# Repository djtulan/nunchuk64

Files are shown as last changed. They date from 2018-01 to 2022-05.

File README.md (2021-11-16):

Nunchuk64

Nunchuk64 is a converter or adapter to connect a Wii Nunchuk or a Nindendo NES Classic Mini Controller
to a Commodore 64. The circuit converts two Nintendo Controllers into two Commodore 64 ones.
All types of the Commodore 64 inputs, which means digital and analog inputs, are available.

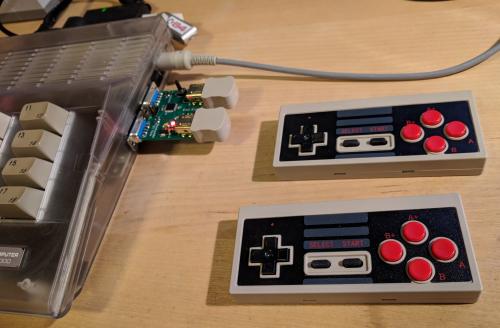
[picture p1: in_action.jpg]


## Introduction Video
User [dukestah] from [Forum64](https://www.forum64.de) made a nice introduction video.
He gives a short introduction how the thing works in basic and demonstrates the functions while playing a game.

INTRODUCITON VIDEO (http://www.youtube.com/watch?v=LK__4W44_HA)

## Layout and PCB
The whole KiCad project is provided inside subfolder ["hardware"](./hardware).

Please feel free to order your own PCBs, Gerber files are here ["gerber"](./hardware/nunchuk64/gerber).

I would be pleased about a small donation: [PAYPAL.ME](https://www.paypal.me/RobertGrasboeck)

If somebody wants order a DIY kit, feel free to contact me: r o b e r t . g r a s b o e c k [at] g m a i l . c o m

## 3D Picture
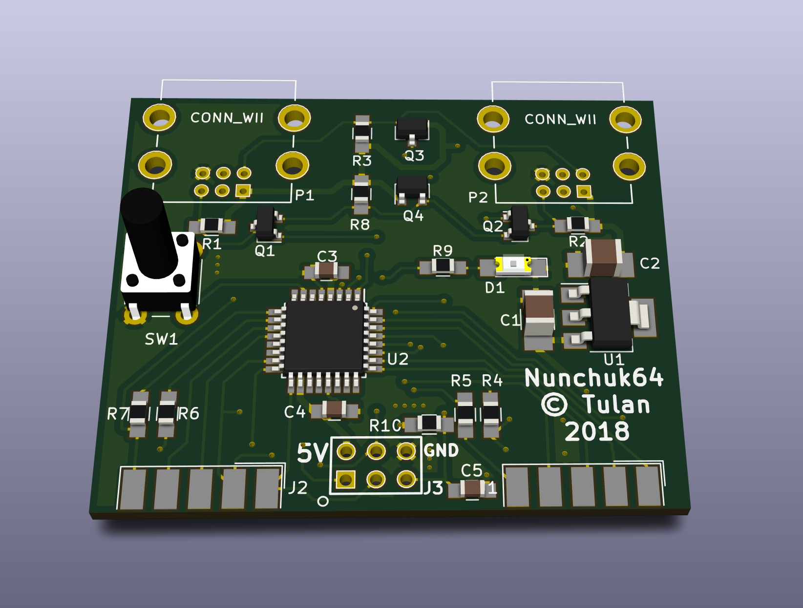
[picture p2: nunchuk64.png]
3d Picture


## Supported and tested Hardware
Currently the following hardware is supported (see [Supported Controllers](./supported_controllers))

## Milestones
- ☑ Tested with a "Nindendo NES Classic Mini Controller" clone
- ☑ Tested with a "original Nindendo Nunchuk Controller"
- ☑ Tested with a "Nindendo Nunchuk Controller" clone
- ☑ Tested with different other NES/SNES Classic Mini clones

## Dependecies
- KiCad to work in schematic and layout (see [KiCad](http://kicad.org/))
- avr-gcc toolchain for compiling the firmware

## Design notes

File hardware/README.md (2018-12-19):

Hardware
==============
In this folder you can find all the needed parts to order the pcb.
The subfolder "nunchuk64" hold the KiCad project and Gerber files.

BOM
---
| Name |Quantity|Value |Footprint |
| ---|---|---|---|
| U1 | 1 |AMS1117-3V3 |SOT-223 |
| U2 | 1 |ATMEGA328P-AU |TQFP-32_7x7mm_Pitch0.8mm |
| C1,C2 | 2 |22uF Tantalum |Tantalum_Case-A_EIA-3216-18 |
| C3,C4,C5 | 3 |100n |0805 |
| D1 | 1 |LED |LED_1206 |
| J1,J2 | 2 |DB9_Female |DSUB-9 EdgeMount_Pitch 2.77mm |
| J3 | 1 |2x3 pin | | 
| P1,P2 | 2 |CONN_WII |Connector_Wii |
| Q1,Q2,Q3,Q4 | 4 |BSS138 |SOT-23 |
| R9 | 1 |220 |0805 |
| R4,R5,R6,R7,R10| 5 |10K |0805 |
| R1,R2,R3,R8 | 4 |2,2K |0805 |
| SW | 1 |SW_Push |Buttons Switch 6mm 13mm lenght|

The ready PCBs
--------------
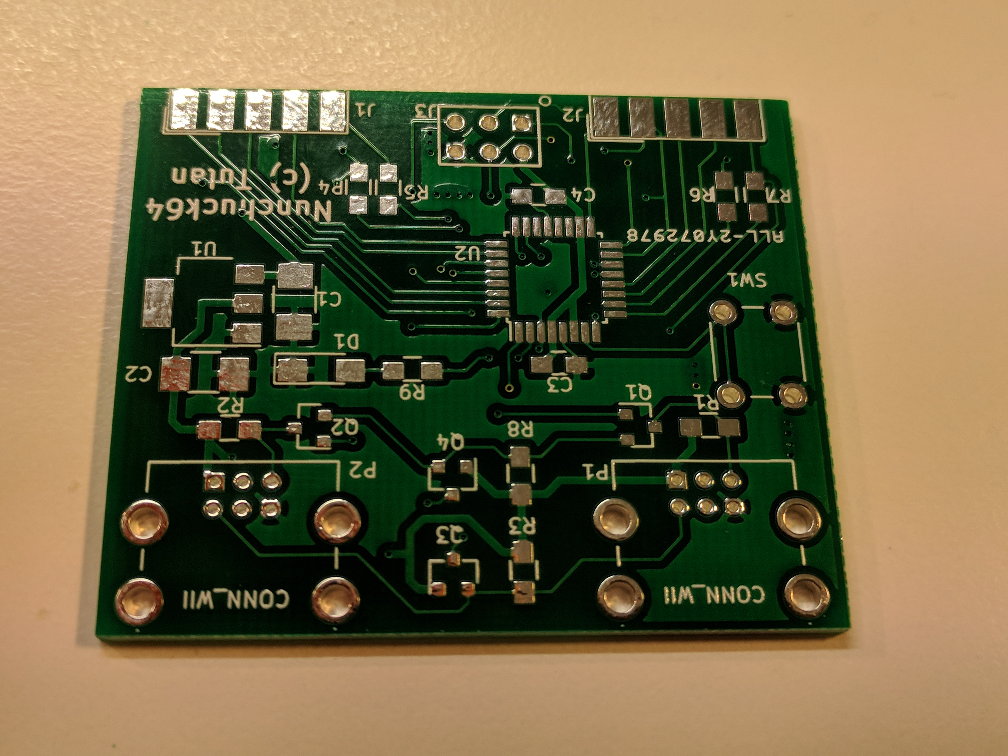
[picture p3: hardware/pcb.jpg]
PCB


PCB with parts
--------------
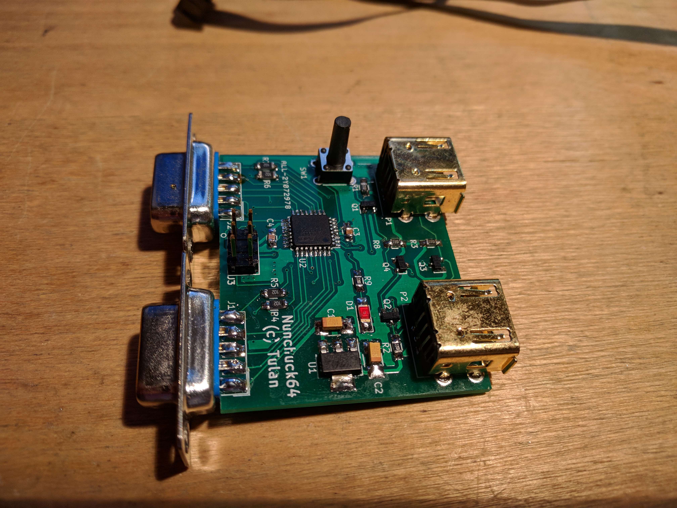
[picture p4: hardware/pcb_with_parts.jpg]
PCB with parts


connected to C64:
--------------
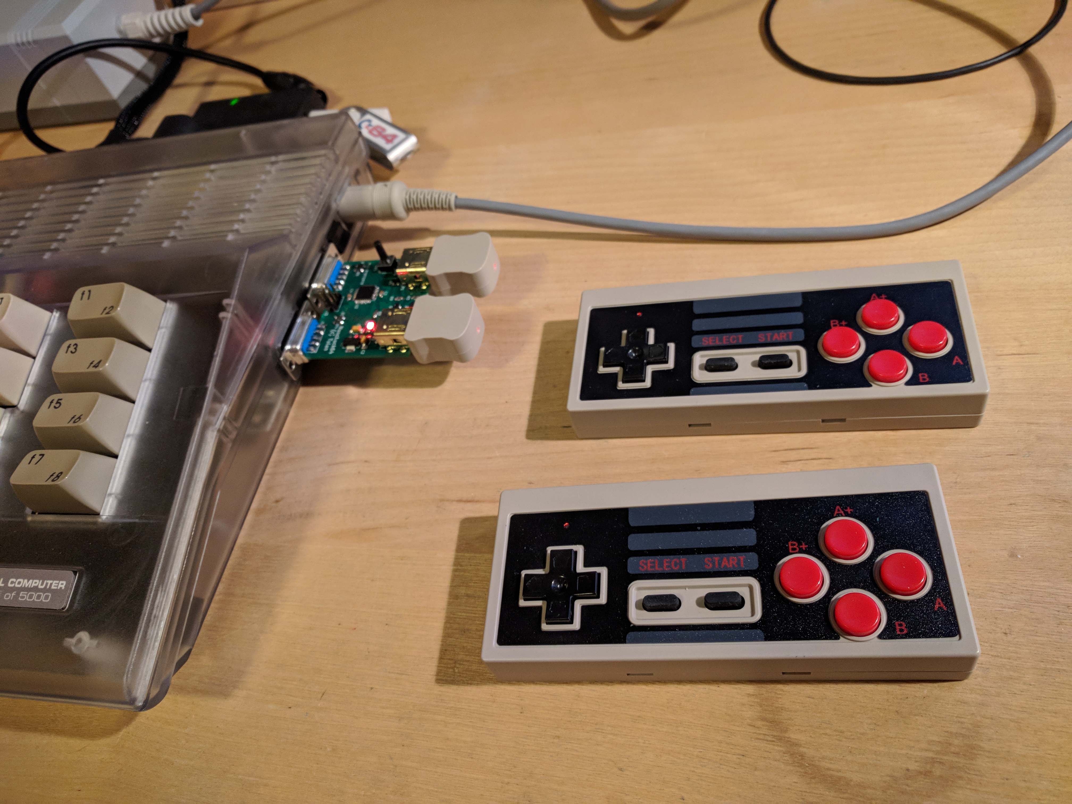
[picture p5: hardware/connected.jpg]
connected


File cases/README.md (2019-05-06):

Nunchuk64 Cases
==============

There are already some cases available for the Nunchuk64.

Case by hackup (https://www.hackup.net/)
----------------------------------------
A realy nice case for friends of 3D printing.
https://www.thingiverse.com/thing:3560915
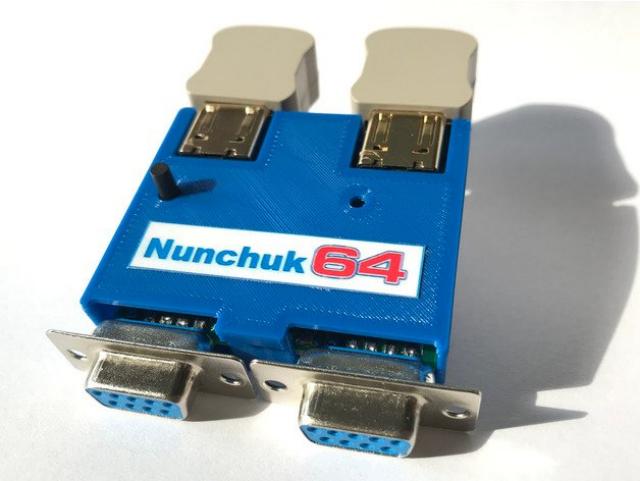
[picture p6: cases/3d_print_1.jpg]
3d_1

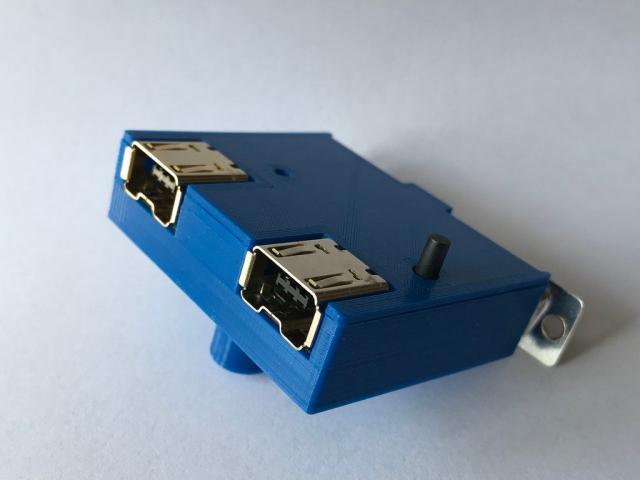
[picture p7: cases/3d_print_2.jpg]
3d_2

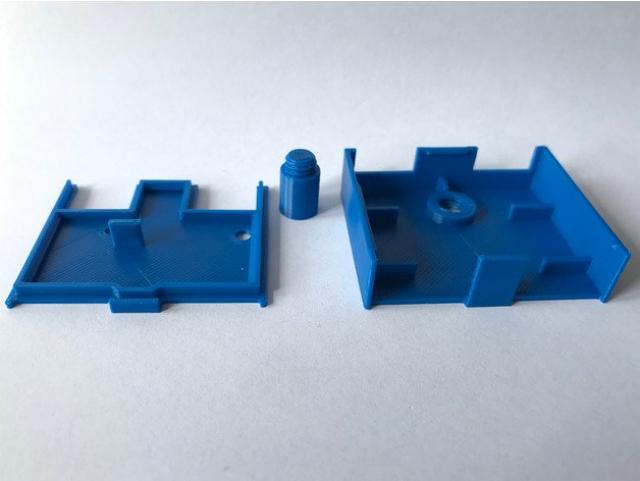
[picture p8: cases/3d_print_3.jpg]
3d_3


Case by plexilaser (Michael Schön)
----------------------------------
A case made from acrylic glass is available at the plexolaser shop:
https://www.plexilaser.de/Acrylgehaeuse-fuer-Nunchuck64-Adapter-Teilesatz

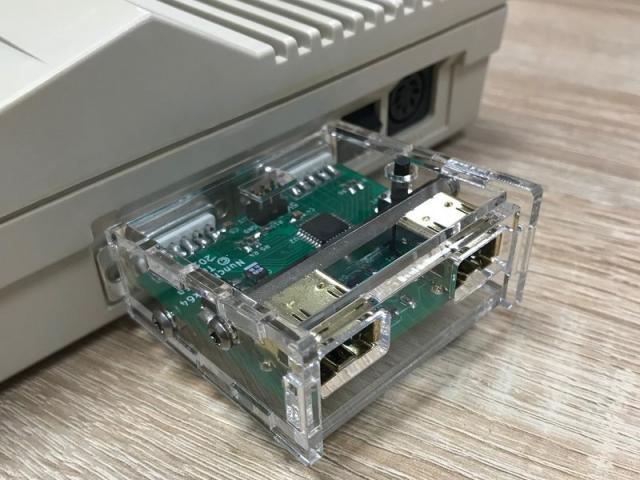
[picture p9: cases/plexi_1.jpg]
plexi_1

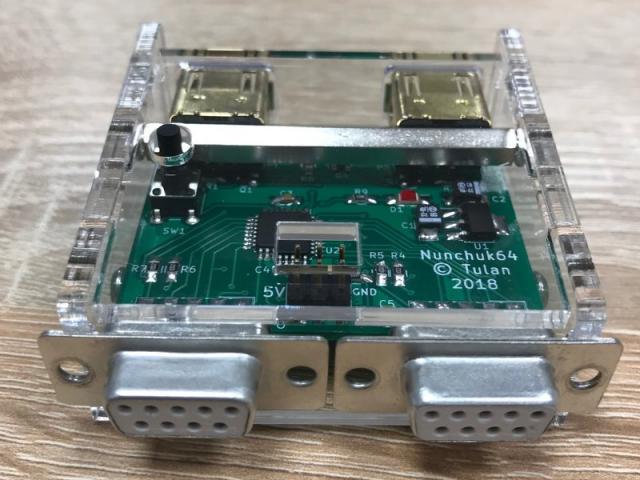
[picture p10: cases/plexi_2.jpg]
plexi_2


Case made from an universal case by Dirk Willke
----------------------------------------------
This nice case is made from a universal case available at conrad.

https://www.conrad.de/de/strapubox-2024-universal-gehaeuse-72-x-50-x-26-abs-schwarz-1-st-522635.html

Strapubox 2024 Universal-Gehäuse 72 x 50 x 26 ABS Schwarz
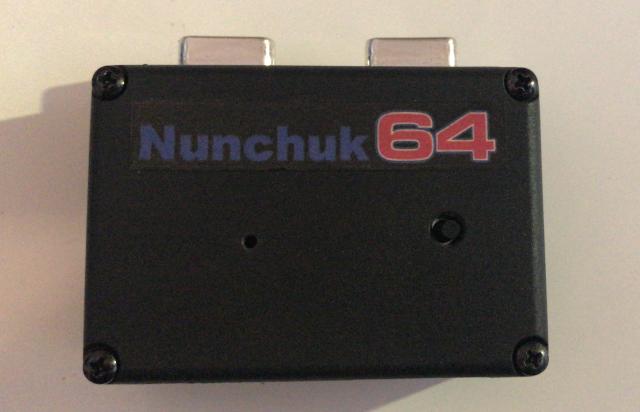
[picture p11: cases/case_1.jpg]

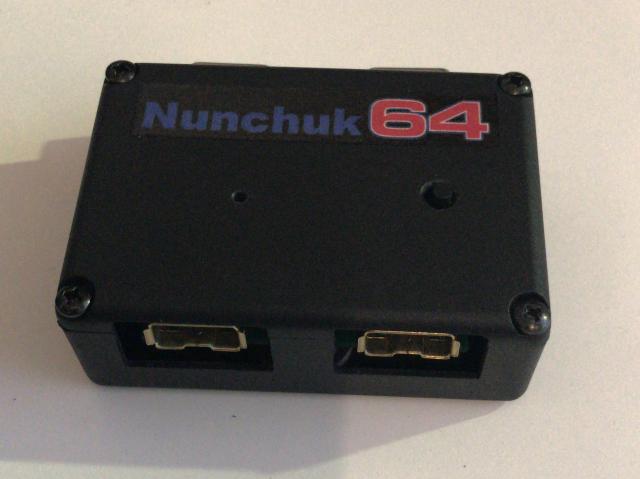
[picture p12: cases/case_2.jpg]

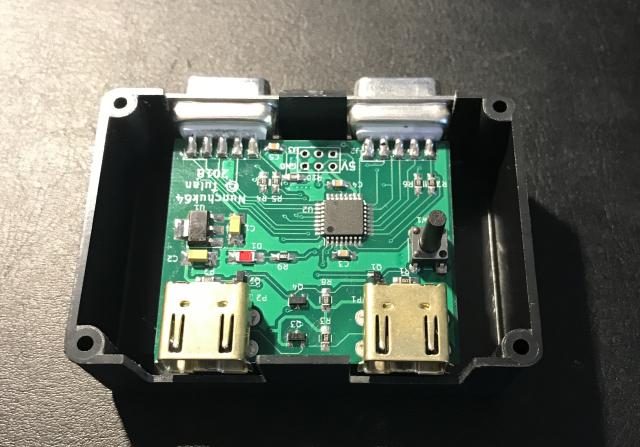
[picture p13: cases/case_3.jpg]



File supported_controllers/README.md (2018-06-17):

# Supported Controllers
This is an overview of all tested controllers.
Since they all mostly use the same datasets, it is very likely that other controllers will work too.

### Modes
Pressing the pushbutton switches the Nunchuk64 to different modes.

- Mode OFF ... LED is OFF
- Mode ON  ... LED is ON
- Mode F1  ... LED flashes 1 time
- Mode F2  ... LED flashes 2 times

Depending on the mode the controllers behaves differently.

### Possible Controls
Nunchuk64 can perform these different controls on each individual C64 Control Port:

- UP (Joystick Up)
- DOWN (Joystick Down)
- LEFT (Joystick Left)
- RIGHT (Joystick Right)
- FIRE (Fire Button)
- AUTOFIRE  (automatic Fire Button)
- PADDLE X
- PADDLE Y
- FIRE2 (5V on Paddle X)
- AUTOFIRE2 BUTTON
- FIRE3 (5V on Paddle Y)
- AUTOFIRE3

An extra function is SPACE, which triggers FIRE on controller port 1.
This is very handy because you can use it to press the space bar.
For FIRE2 / FIRE3 C64s analog paddle input X,Y are used,
similar the Cheetah Annihilator Joystick.
See https://www.c64-wiki.de/wiki/Joystick#Weitere_Feuerkn.C3.B6pfe

### Joystick Swapping
A long press on the button changes the ports. Port 1 becomes 2 and Port 2 becomes 1.
Another long press, changes them back. It is indicated by a two times flash or one time flash.

## NES Classic Mini Clone
Wireless Controller for Nintendo NES Mini Classic Edition.

Seen here: https://www.ebay.com/itm/272765627224
> Button A+ and B+ are same as A and B but with autofire!

> Nintendo original NES Classic Mini is using the driver_wii_classic!

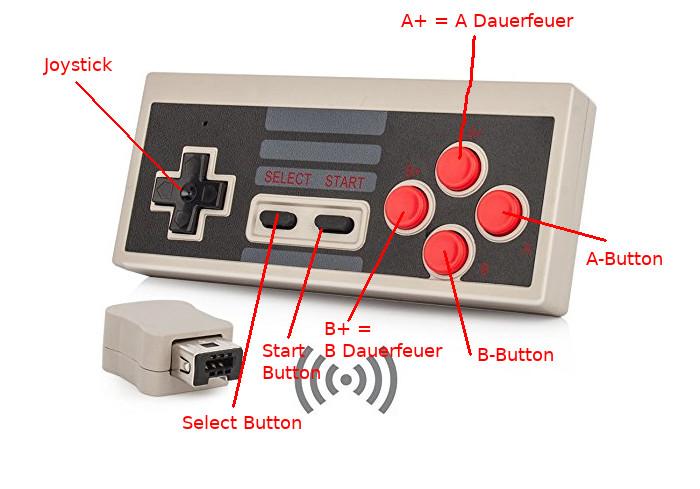
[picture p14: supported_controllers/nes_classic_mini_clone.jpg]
NES Classic Mini Clone


DRIVER: [driver_wii_classic.c]

| Item |Mode OFF  |Mode ON |Mode F1 |Mode F2 |
| ---|---|---|---|---|
| Joystick UP |UP |UP |- |- |
| Joystick DOWN |DOWN |DOWN |- |- |
| Joystick LEFT |LEFT |LEFT |LEFT |- |
| Joystick RIGHT|RIGHT |RIGHT |RIGHT |- |
| A |UP |FIRE2 |UP |LEFT |
| B |FIRE |FIRE |DOWN |RIGHT |
| A+ |UP |FIRE2 |UP |LEFT |
| B+ |FIRE |FIRE |DOWN |RIGHT |
| SELECT |FIRE |FIRE |FIRE |FIRE |
| START |SPACE |SPACE |SPACE |SPACE |

## Original NESS Classic Mini
Wired Controller for Nintendo NES Mini Classic Edition.

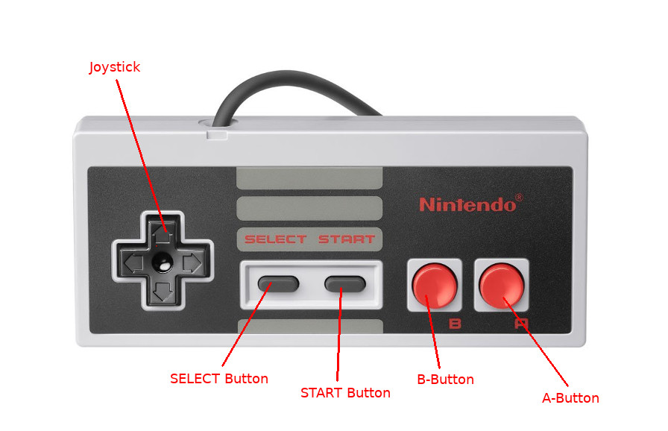
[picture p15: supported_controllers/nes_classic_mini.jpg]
NES Classic Mini


DRIVER: [driver_wii_classic.c]

| Item |Mode OFF  |Mode ON |Mode F1 |Mode F2 |
| ---|---|---|---|---|
| Joystick UP |UP |UP |- |- |
| Joystick DOWN |DOWN |DOWN |- |- |
| Joystick LEFT |LEFT |LEFT |LEFT |- |
| Joystick RIGHT|RIGHT |RIGHT |RIGHT |- |
| A |UP |FIRE2 |UP |LEFT |
| B |FIRE |FIRE |DOWN |RIGHT |
| SELECT |FIRE |FIRE |FIRE |FIRE |
| START |SPACE |SPACE |SPACE |SPACE |

## SNES Classic Mini Clone
Wireless Controller for Nintendo SNES Mini Classic Edition.

Seen here: https://www.ebay.com/itm/162874713501

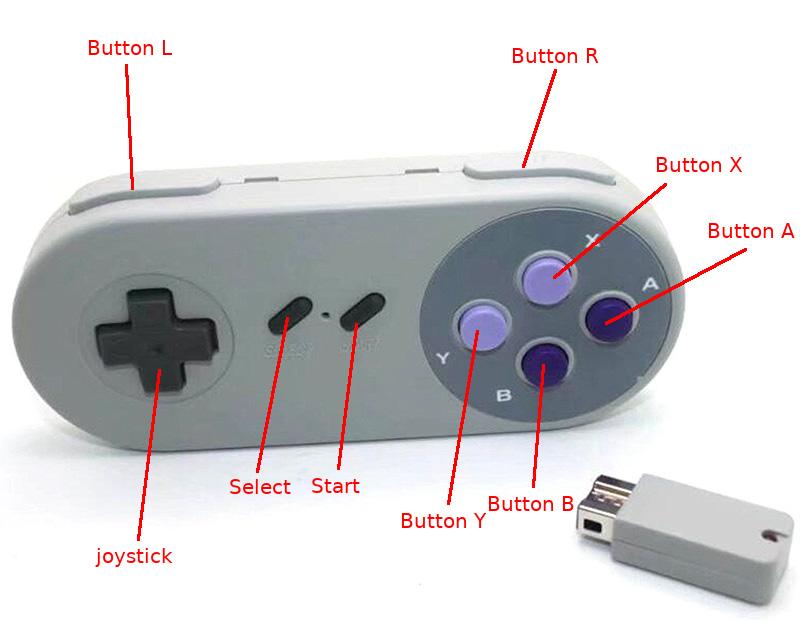
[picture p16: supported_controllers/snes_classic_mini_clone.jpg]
SNES Classic Mini Clone


Wired Controller for Nintendo SNES Mini Classic Edition.

Seen here: https://www.ebay.at/itm/222674575659

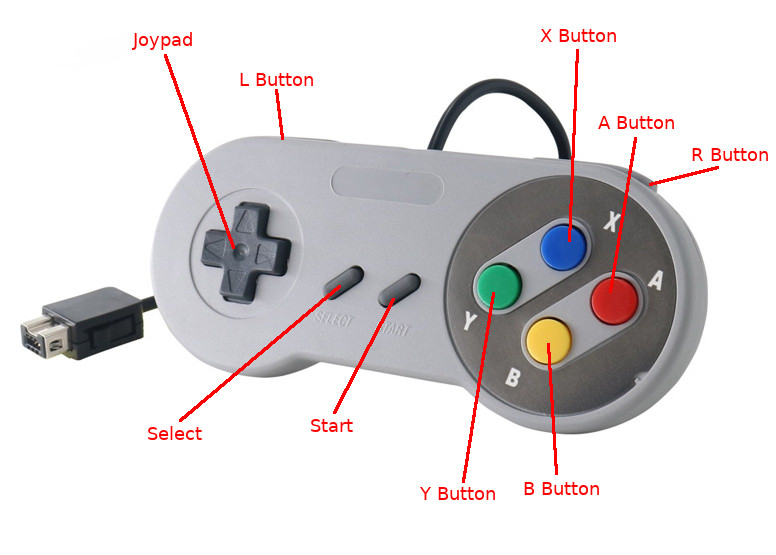
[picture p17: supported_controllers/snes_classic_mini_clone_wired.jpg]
SNES Classic Mini Clone


DRIVER: [driver_wii_classic.c]

| Item |Mode OFF  |Mode ON |Mode F1 |Mode F2 |
| ---|---|---|---|---|
| Joystick UP |UP |UP |- |- |
| Joystick DOWN |DOWN |DOWN |- |- |
| Joystick LEFT |LEFT |LEFT |LEFT |- |
| Joystick RIGHT|RIGHT |RIGHT |RIGHT |- |
| A |UP |FIRE2 |DOWN |RIGHT |
| B |FIRE |FIRE |UP |LEFT |
| X |FIRE2 |FIRE3 |FIRE |FIRE |
| Y |AUTOFIRE  |UP |AUTOFIRE  |- |
| SELECT |FIRE |FIRE |FIRE |FIRE |
| START |SPACE |SPACE |SPACE |SPACE |
| L |LEFT |LEFT |FIRE |- |
| R |RIGHT |RIGHT |FIRE |- |

## Wii classic controller
Wii Classic Controller for Nintendo Wii Remote. (Wired)

Seen here: https://www.ebay.com/itm/291645811767

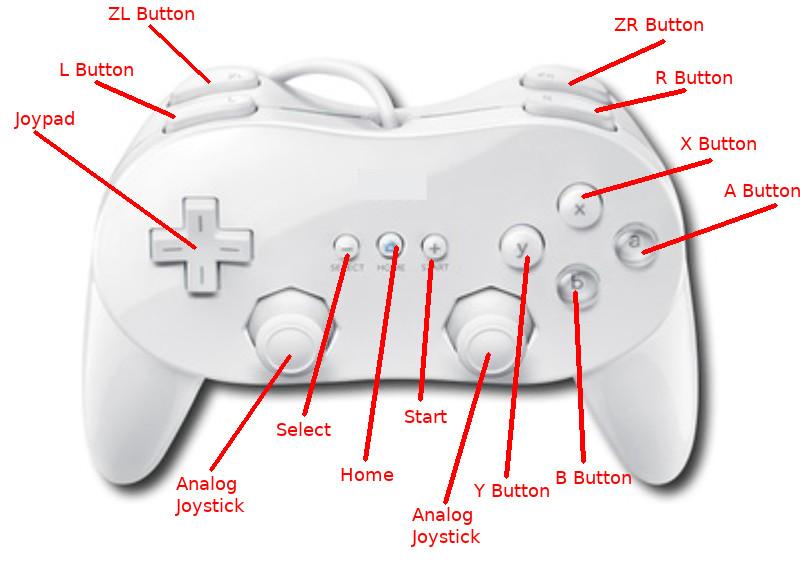
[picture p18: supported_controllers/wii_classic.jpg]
Wii Classic Clone


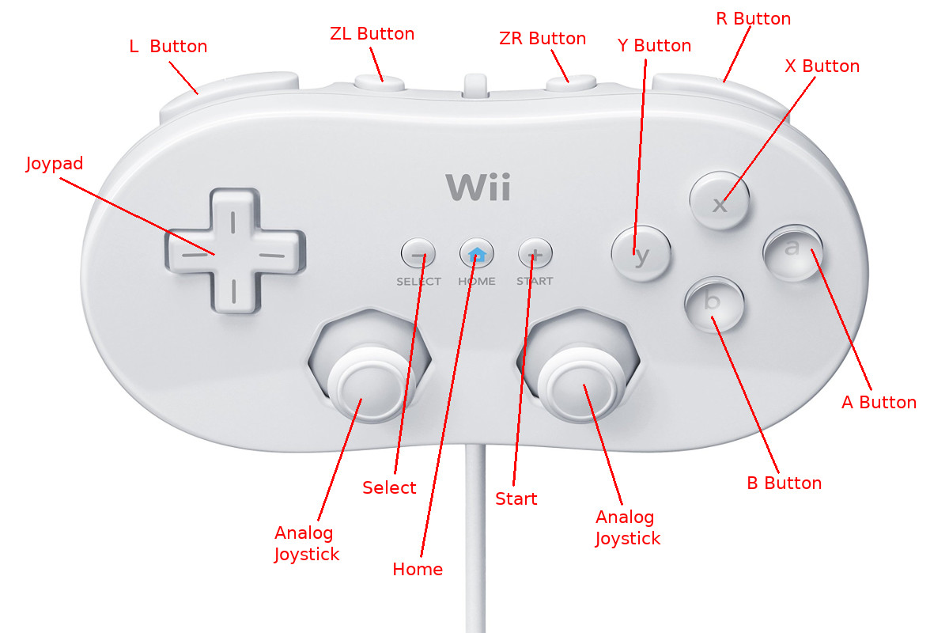
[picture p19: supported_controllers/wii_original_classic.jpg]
Wii Classic


DRIVER: [driver_wii_classic.c]

| Item |Mode OFF  |Mode ON |Mode F1 |Mode F2 |
| ---|---|---|---|---|
| Joystick UP |UP |UP |- |- |
| Joystick DOWN |DOWN |DOWN |- |- |
| Joystick LEFT |LEFT |LEFT |LEFT |- |
| Joystick RIGHT|RIGHT |RIGHT |RIGHT |- |
| A |UP |FIRE2 |DOWN |RIGHT |
| B |FIRE |FIRE |UP |LEFT |
| X |FIRE2 |FIRE3 |FIRE |FIRE |
| Y |AUTOFIRE  |UP |AUTOFIRE  |- |
| SELECT |FIRE |FIRE |FIRE |FIRE |
| HOME |FIRE2 |FIRE2 |FIRE2 |- |
| START |SPACE |SPACE |SPACE |SPACE |
| L |LEFT |LEFT |FIRE |- |
| ZL |- |- |- |- |
| R |RIGHT |RIGHT |FIRE |- |
| ZR |- |- |- |- |
| LX (Analog) |LEFT/RIGHT|LEFT/RIGHT|LEFT/RIGHT|PADDLE X  |
| LY (Analog) |UP/DOWN |UP/DOWN |UP/DOWN |PADDLE Y  |
| RX (Analog) |- |- |- |- |
| RY (Analog) |- |- |- |- |

## Wii Nunchuck
Wii Nunchuck Controller for Nintendo Wii Remote

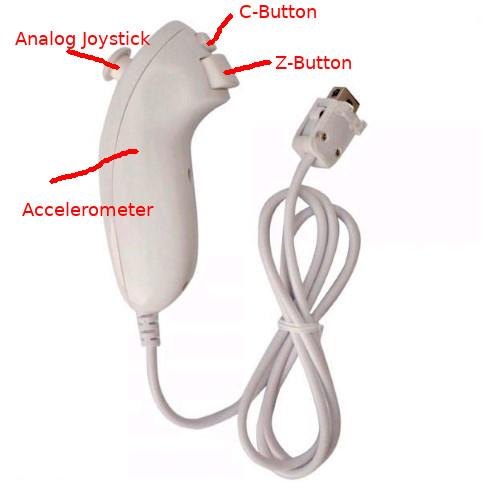
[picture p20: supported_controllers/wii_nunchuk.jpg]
Wii Nunchuk


DRIVER: driver_nunchuk.c

| Item |Mode OFF  |Mode ON |Mode F1 |Mode F2 |
| ---|---|---|---|---|
| Analog Joy X  |LEFT/RIGHT|- |- |PADDLE X  |
| Analog Joy Y  |UP/DOWN |- |- |PADDLE Y  |
| Accel X |- |LEFT/RIGHT|PADDLE X  |- |
| Accel Y |- |UP/DOWN |PADDLE Y  |- |
| Accel Z |- |- |- |- |
| C |AUTOFIRE  |AUTOFIRE  |AUTOFIRE  |AUTOFIRE  |
| Z |FIRE |FIRE |FIRE |FIRE |

[driver_nes_classic.c]: <https://github.com/djtulan/nunchuk64/blob/master/src/driver_nes_classic.c>
[driver_wii_classic.c]: <https://github.com/djtulan/nunchuk64/blob/master/src/driver_wii_classic.c>

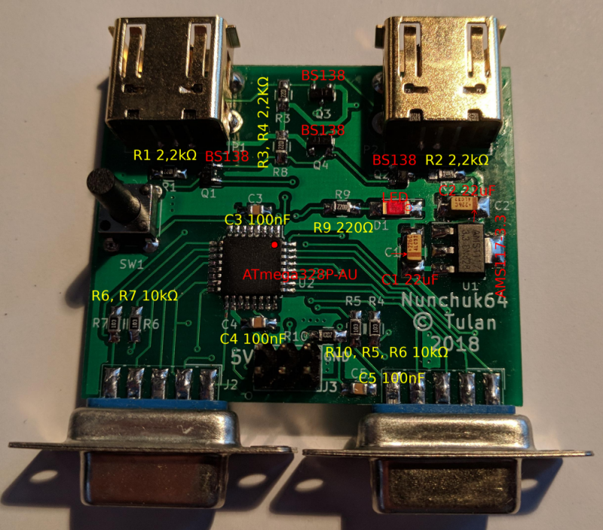
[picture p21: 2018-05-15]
hardware/part_placement.png

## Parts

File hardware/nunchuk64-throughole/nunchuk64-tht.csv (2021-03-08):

Item | Qty | Reference(s) | Value | Footprint | Mouser
1 | 2 | C1, C2 | 22uF | Capacitor_THT:CP_Radial_D5.0mm_P2.50mm | 667-ECE-A1CKS220I
2 | 2 | C3, C5 | 100nF | Capacitor_THT:C_Disc_D5.0mm_W2.5mm_P5.00mm | 594-K104K15X7RF53H5
3 | 1 | D1 | LED | LED_THT:LED_D3.0mm | 859-LTL-4291N
4 | 2 | J1, J2 | DB9_Female | Connectors_DSub:DSUB-9_Female_EdgeMount_Pitch2.77mm | 523-L77SDEH09SOL2RM5
5 | 1 | J3 | Not Used | nunchuk_commodore:AVR-ISP-6-TH
6 | 2 | P1, P2 | CONN_WII | Connector_Wii:CONN_WII
7 | 4 | Q1, Q2, Q3, Q4 | 2N7000 | Package_TO_SOT_THT:TO-92 | 512-2N7000
8 | 1 | R9 | 220 | Resistor_THT:R_Axial_DIN0207_L6.3mm_D2.5mm_P7.62mm_Horizontal | 71-CCF07220RJKE36
9 | 1 | R10 | 10k | Resistor_THT:R_Axial_DIN0207_L6.3mm_D2.5mm_P7.62mm_Horizontal | 71-CCF0710K0JKE36
10 | 1 | RN1 | 2K2 | Resistor_THT:R_Array_SIP5 BUSSED | 652-4605XAP1-222LF
11 | 1 | RN2 | 10K_Pack04_SIP | Resistor_THT:R_Array_SIP8 BUSSED | 652-4608M-2LF-10K
12 | 1 | SW1 | SW_Push | Buttons_Switches_ThroughHole:SW_PUSH_6mm_h13mm | 706-95C06B3T
13 | 1 | U1 | LP2950-3.3_TO92 | Package_TO_SOT_THT:TO-92_Inline | 595-LP2950-33LPRE3
14 | 1 | U2 | ATmega328P-PU | Package_DIP:DIP-28_W7.62mm | 556-ATMEGA328P-PN

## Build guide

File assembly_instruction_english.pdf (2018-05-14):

Brief instructions building Nunchuk64 (https://www.forum64.de/index.php?thread/80731-sammelbestellung-nunchuk64/)

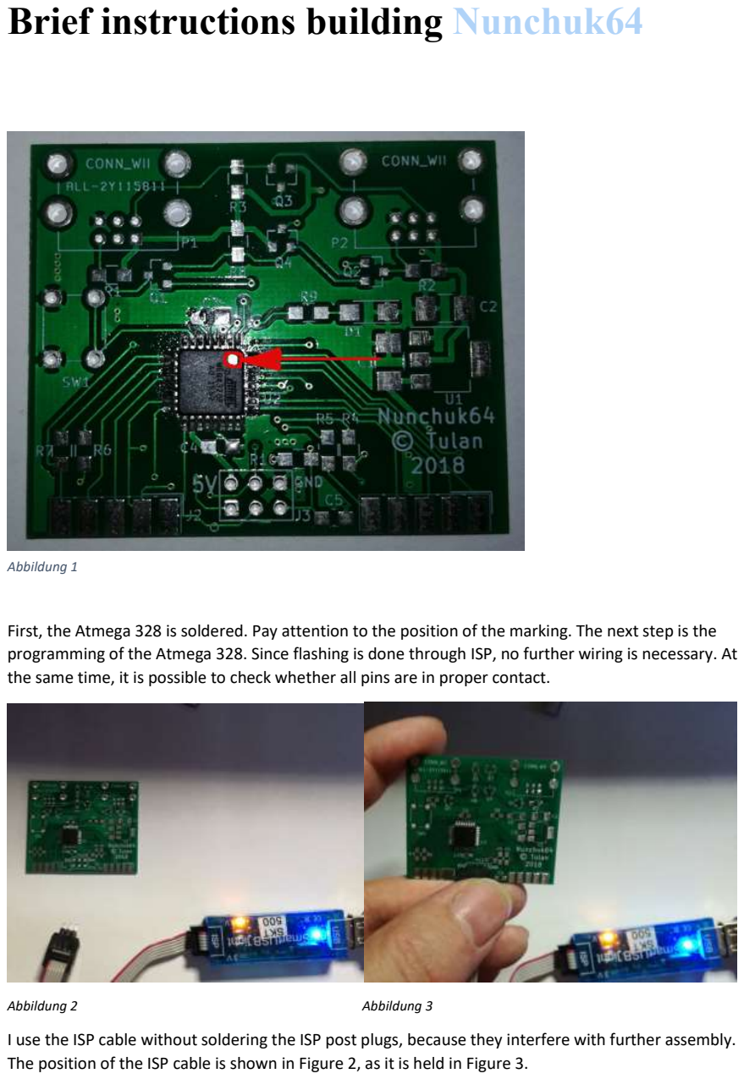
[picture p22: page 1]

Als

First, the Atmega 328 is soldered. Pay attention to the position of the marking. The next step is the programming of the Atmega 328. Since flashing is done through ISP, no further wiring is necessary. At the same time, it is possible to check whether all pins are in proper contact.

Abbildung 2 | Abbildung 3

I use the ISP cable without soldering the ISP post plugs, because they interfere with further assembly. The position of the ISP cable is shown in Figure 2, as it is held in Figure 3.

Abbildung 1

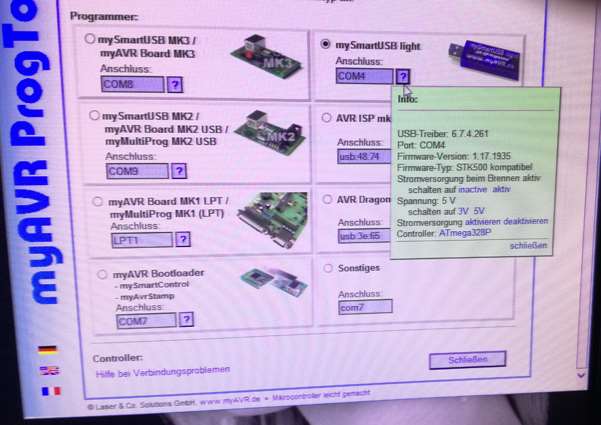
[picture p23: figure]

I am flashing the whole thing with mySmartUSB light. In the tool, click on the question mark. If everything is soldered correctly, the recognized controller appears in the info box. Click on the controller the ATmega328 to take it for programming. In the program menu, select the hex file. Disable the burning of the fuses. (Factory settings are retained)

Similarly, the whole thing works with the TL866 in ISP mode.

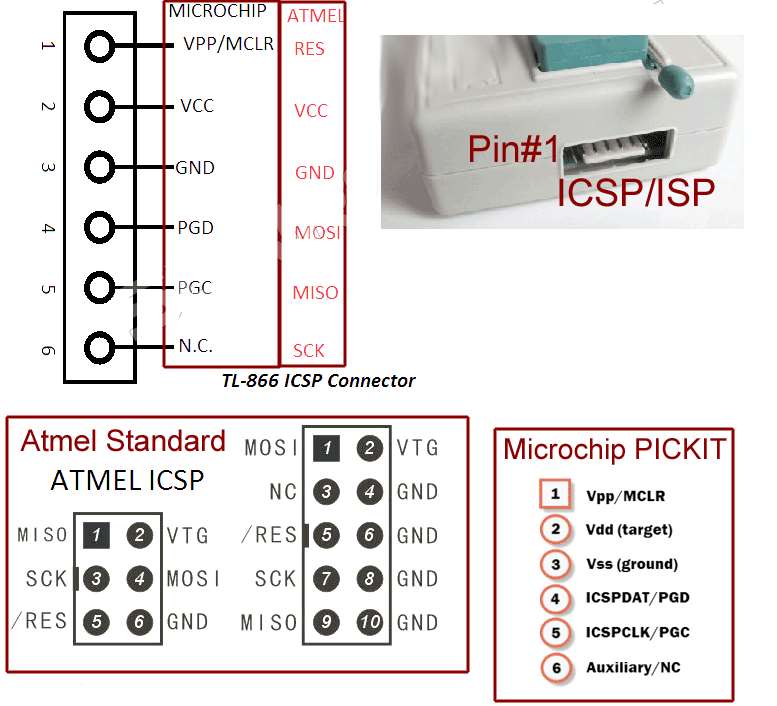
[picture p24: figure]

If you work with avr-dude:
avrdude.exe -c usbasp -p m328p -u -U flash:w:nunchuk64.hex

Please note that the ATMega has to be supplied with power during burning (Jumper "VTarget").

For all who flash their ATMEGA with USBasp, please set the jumper for "Slow SCK", otherwise avrdude does not find the chip. In my case that was JP3.

After flashing, the resistors are assembled:
R1, R2, R3, R8 | 2,2 Kohm
R4, R5, R6, R7, R10 | 10 Kohm
R9 | (dropping resistor LED) 220 Ohm

Then the capacitors:

C1, C2 | 22 µF - Pay attention to polarity!

Polarity of SMD-capacitors

C3, C4, C5 | 100 nF

Now the LED follows:

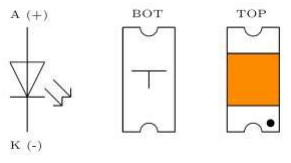
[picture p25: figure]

The tiny point (cathode = - pole) can only be seen before soldering! If you are not sure, you should find the polarity with a 5V source and a 220 ohm resistor.
Then the 3.3V regulator and the 4 transistors are soldered. Finally, the WII sockets,
the 9-pin-sockets, the ISP header and the 4 buttons are soldered in place.

Note on the Sub9 sockets: Solder the first socket at two points. Attach the second one without soldering and connect the board to the C64 with both connectors to achieve the correct distance. Solder the second jack as well. Now the adapter can be removed to solder the remaining pins.

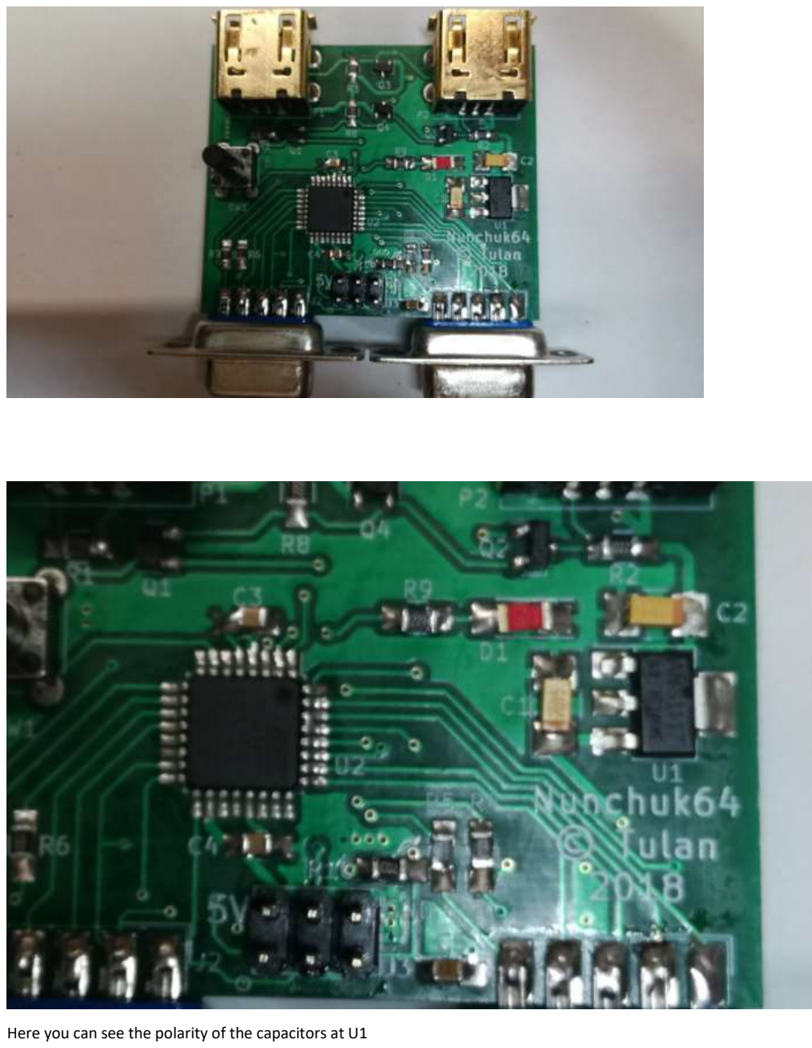
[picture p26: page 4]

Here you can see the polarity of the capacitors at U1

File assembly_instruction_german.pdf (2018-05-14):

Kurzanleitung Aufbau Nunchuk64 (https://www.forum64.de/index.php?thread/80731-sammelbestellung-nunchuk64/)

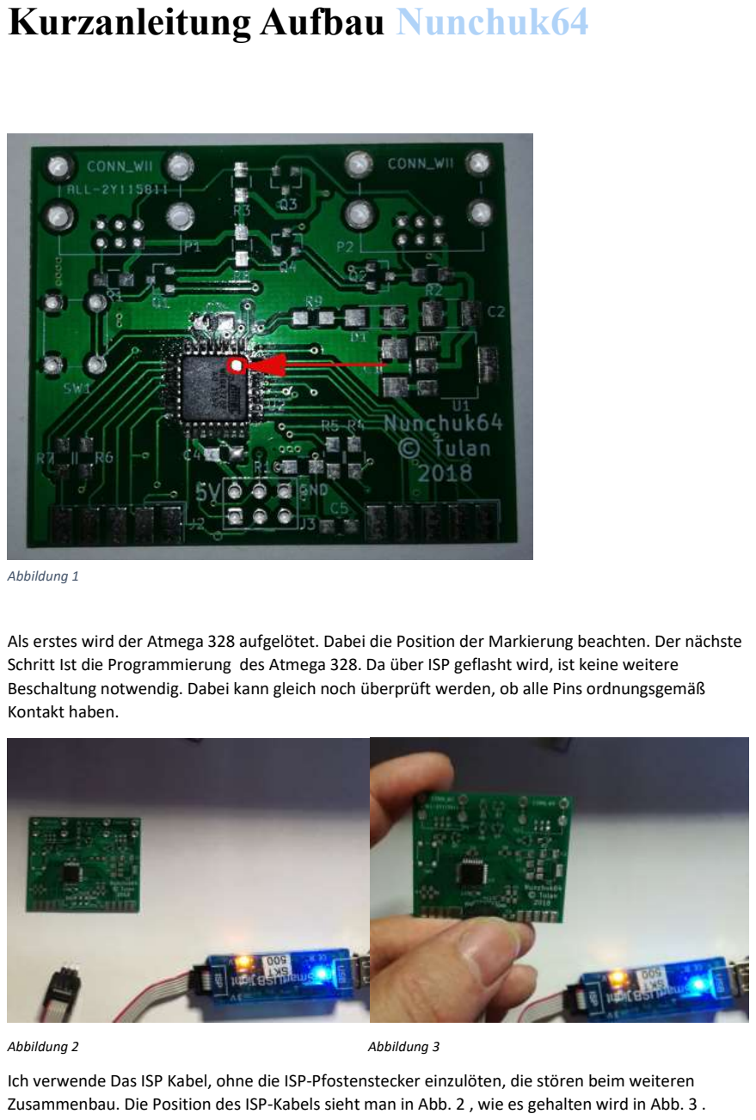
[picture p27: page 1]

Als

Als erstes wird der Atmega 328 aufgelötet. Dabei die Position der Markierung beachten. Der nächste Schritt Ist die Programmierung des Atmega 328. Da über ISP geflasht wird, ist keine weitere Beschaltung notwendig. Dabei kann gleich noch überprüft werden, ob alle Pins ordnungsgemäß Kontakt haben.

Abbildung 2 | Abbildung 3

Ich verwende Das ISP Kabel, ohne die ISP-Pfostenstecker einzulöten, die stören beim weiteren Zusammenbau. Die Position des ISP-Kabels sieht man in Abb. 2 , wie es gehalten wird in Abb. 3 .

Abbildung 1

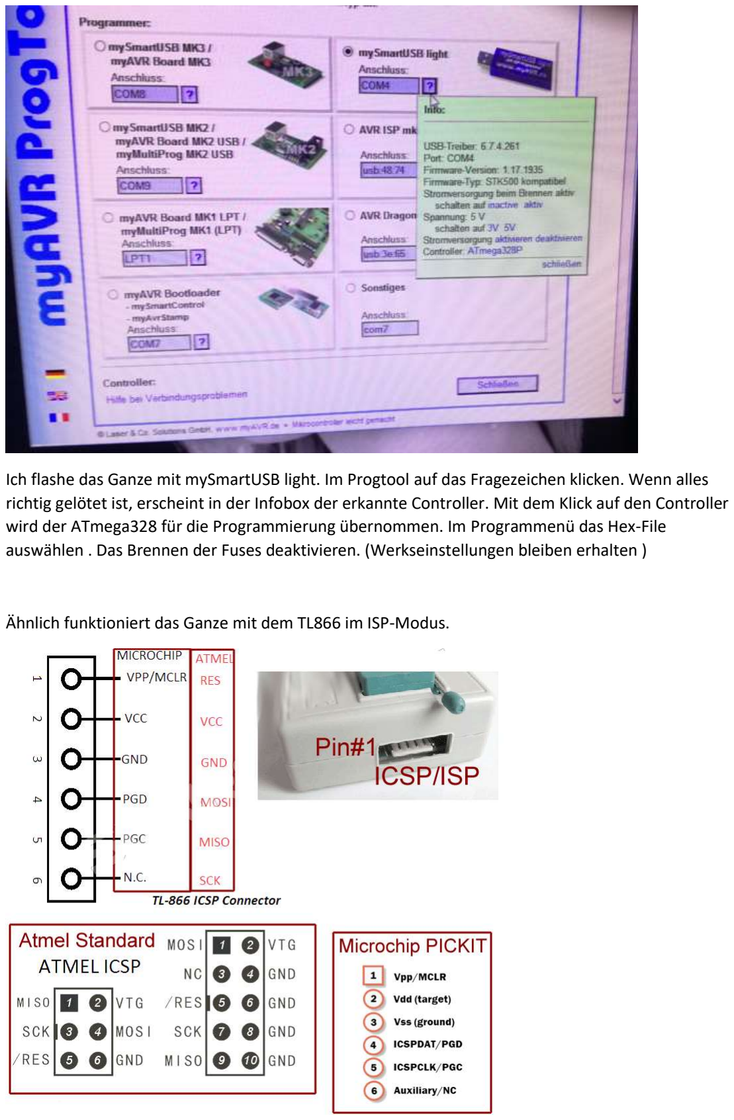
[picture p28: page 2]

Ich flashe das Ganze mit mySmartUSB light. Im Progtool auf das Fragezeichen klicken. Wenn alles richtig gelötet ist, erscheint in der Infobox der erkannte Controller. Mit dem Klick auf den Controller wird der ATmega328 für die Programmierung übernommen. Im Programmenü das Hex-File auswählen . Das Brennen der Fuses deaktivieren. (Werkseinstellungen bleiben erhalten )

Ähnlich funktioniert das Ganze mit dem TL866 im ISP-Modus.

Wer mit avr-Dude arbeitet:
avrdude.exe -c usbasp -p m328p -u -U flash:w:nunchuk64.hex
Bitte beachten, dass der ATMega während des Brennens mit Spannung versorgt werden muss (entsprechenden Jumper "VTarget" setzen).

Für alle, die ihren ATMEGA mit USBasp flashen, bitte den Jumper für "Slow SCK" setzen, sonst findet avrdude den Chip nicht. In meinem Fall war das JP3.

Nach dem Flashen werden die Widerstände bestückt:
R1, R2, R3, R8 | 2,2 Kohm
R4, R5, R6, R7, R10 | 10 Kohm
R9 | (Vorwiderstand LED) | 220 Ohm

Danach die Kondensatoren:

C1, C2 | | 22 µF - Polung beachten !

Polung von SMD-Kondensatoren

C3, C4, C5 | 100 nF

Jetzt folgt die LED:

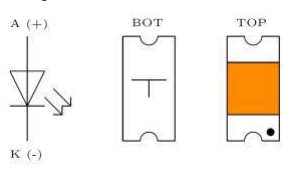
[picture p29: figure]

Den winzigen Punkt ( Kathode = - Pol )sieht man nur vor dem Löten ! Wer sich nicht sicher ist, sollte die Polung mit einer 5V Quelle und einem 220 Ohm Vorwiderstand herausfinden.

Danach wird der 3,3V Regler und die 4 Transistoren eingelötet.

Zum Schluss werden Die WII-Buchsen, Die 9-pol-Buchsen, der ISP- Header und der Microtaster eingelötet.
Hinweis zu den Sub9 – Buchsen: Erst mal eine Buchse an zwei Punkten anheften und die zweite nur aufstecken. Dann am C64 anschließen ( wegen der Abstände) und dann die zweite Buchse ebenfalls anheften. Nun kann der Adapter vom C64 entfernt werden und die restlichen Lötstellen gelötet werden.

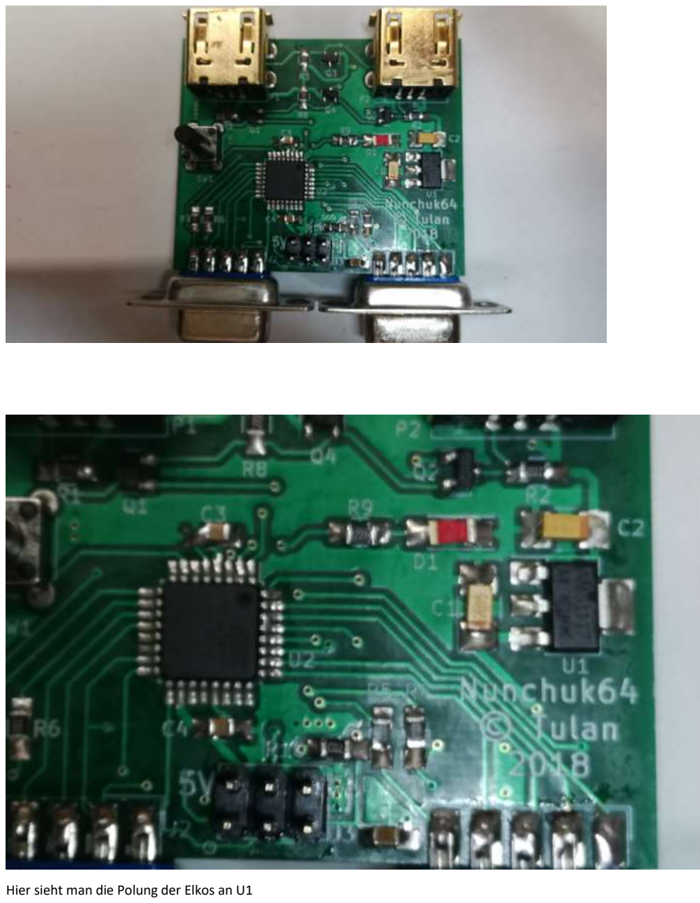
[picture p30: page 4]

Hier sieht man die Polung der Elkos an U1

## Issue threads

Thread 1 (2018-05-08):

8bitdo Controllers are not recognized

djtulan, 2018-05-08:
The famous 8Bitdo wireless controllers for Wii and Nintendo NES classic Mini are sadly not regonized.

djtulan, 2018-05-15:
- Fixed with Release 1.1.0

Closed 2018-05-15.

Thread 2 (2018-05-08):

new (black) Nunchuks are not working

djtulan, 2018-05-08:
Some of the original Nintendo Nunchuks are not working yet.

djtulan, 2018-08-23:
Since the newer Nunchuks (also for Wii U) need a higher I²C speed. It cannot be reached with the ATmega.

penfold42, 2019-10-16:
I know this is an old issue...

What i2c clock do they need ?
Would running the avr at 8MHz help ?

Closed 2018-08-23.

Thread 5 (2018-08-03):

tl866a fusebits risc of locking oneself out. Should be in the docs.

bwack, 2018-08-03:
I'm making a handful of the boards and programming them with the TL866A.
Half of the boards programmed fine, but the rest did not.
After research it was the fusebits in minipro that got changed. Also I got them back to life by supplying a clock signal in on the button/XTAL and reprogramming them.

I thought the .hex file carried the fusebits, but no. These have to be set manually, and I found them in the makefile.  Could you please put the fusebits information in the programming documentation and together with the instructions for using tl866a?

djtulan, 2018-08-23:
bwack is absolutely right. Take care of the fusebits. Best is not to play around with it. Leave the default fusebits for ATmega328p.

bwack, 2018-09-06:
Maybe it is not the correct place to ask, but did you write the I2C communication yourself ? I'm looking into adding I2C on an ATTINY for my c64 saver addon board project.

Closed 2022-05-26.

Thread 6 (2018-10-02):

LED is flashing only, no function

VintageProject, 2018-10-02:
When trying the Nunchuk64 with Nintendo Nunchuks, I found that the LED is flashing constantly with approx. 1 Hz, much like the basic Blinky program. The flashing happens no matter if a C64 is hooked up or a Nunchuk.
If I power the board from a bench PSU with 5V via the DB9 or the programming header, it also flashes.

Although I read that the LED on pin 2 of the ATMega328P is hooked up for debugging, I couldn't find any documentation on how to read its signal.

What does this constant flashing mean?

I tried reprogramming the MCU with this v1.2.0 release, but it didn't change.
https://github.com/djtulan/nunchuk64/releases

djtulan, 2018-10-03:
The Flashing comes from the Watchdog Timer, which is set to 1sec.
The WDT resets the device if the I2C communication times out -> no anwer.
If no controller is connected and the device flashes with 1Hz, then you have a soldering bug.
Some newer Nunchuks don't work with the Adapter, this could be the issue.

bwack, 2019-10-16:
@VintageProject Are your Nunchucks the black ones with higher I2C frequencies ? Maybe realted issue #2.

VintageProject, 2019-10-17:
@bwack Yes, they're black oney, but I didn't get around measuring anything or diving into the code.
I did test with another controller, and the faulty board didn't seem to work with that, either.

bwack, 2019-10-18:
Faulty board.. I sent two working boards!

VintageProject, 2019-10-18:
You did. I think the microcontroller got knackered somehow.
I have replacements somewhere and I'm going to try and swap it.

As for the function with the Nunchuks, we can close this one here.

Closed 2019-10-18.

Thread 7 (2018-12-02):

Ready made HEX

mamejay, 2018-12-02:
Hello there.  I am good at soldering but terrible on the software side and not sure about compiling the source code.  I am a windows user and have no idea where to start.
Is it possible to get a ready made HEX file for the Atmega chip?
Also on a previous issue you mention to just leave all fuse values alone.  so if using AVRdude I would just use a standard command and leave all fuse values out of the command?
Thanks

djtulan, 2018-12-03:
You don't have to compile it by yourself you can just use the latest release:
https://github.com/djtulan/nunchuk64/releases
There is also the HEX file.

The call for avrdude should look like this, depending on your programmer
I don't know if it is the same for Windows
**avrdude -p atmega328p -c usbtiny -F -v  -v  -U flash:w:nunchuk64.hex**

mamejay, 2018-12-03:
Thank you very much for that.  I feel a bit silly now.

Closed 2018-12-03.

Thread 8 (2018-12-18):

Huge lag on Left and down movements

mamejay, 2018-12-18:
Hi there djtulan.
I managed to make a couple of adapters last night.
They are recognising but I am getting huge lag on left and down movement.  Also slight lag on all other movements but left and down is the worst.
I purchased the following SNES mini controllers.
https://www.ebay.com.au/itm/Wireless-Controller-Gamepad-For-Super-Nintendo-SNES-Classic-Mini-Edition-Console/222907612359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

Any ideas on what could be the issue?  I have use 22uf ceramic caps.  Could this be the issue?
Everything else is exactly as you had in your BOM.  Thanks

djtulan, 2018-12-18:
Hi!

I also got some of these. The quality is not so nice. Do you have always the same lag or is it changing? Maybe it is a contact problem inside the controller? One of mine had troubles with one direction as i remember right. I opened the controller and moved the membrane to the correct position, than it was slightly better.

The 22uF ceramic caps should not cause that troubles.

mamejay, 2018-12-18:
I will test over this week with a Nintendo nunchuk controller I have and see if I get the same problems.  I will also test these controllers on my SNES mini and see if I get similar results.

mamejay, 2018-12-19:
Hi djtulan,
You are correct.  The pads are shit.  I managed to get them workable by adding solder to the contacts on the game pad to make the dpad presses shorter.  This has made them much better to use and lag is pretty much gone now.
Attached are pictures in case others need to do the same.

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

djtulan, 2018-12-19:
Nice hack :+1:   Thank you for the pictures.
I will close the issue now.

Closed 2018-12-19.

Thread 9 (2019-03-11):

Joystick plugs should be on short cable

AdamKlob, 2019-03-11:
Joystick plugs should be on short cable instead of fixed on a board. This way this adapter could be used with most (all?) 8/16 bit computers and not only C64.

djtulan, 2019-03-11:
You can solder some cables instead of soldering the D-SUB Connectors.
Some people integrated the PCB inside a C64 with cables. So both original Joysticks and wireless pads are possible.

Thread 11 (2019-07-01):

Sinclair maybe

gooner2077, 2019-07-01:
Hi it not a issue but more a request.
If you Could modify the hex or 2nd version for Sinclair joystick layout as I noticed it would fit nicely in the joystick slots but I know they are wired differently so just wanted to know if this was possible.

Thanks

Ps
Love this device made one my self.
Mainly because of your great work on this project.

penfold42, 2019-07-01:
It doesn’t look like it has +5v which the nunchuk needs for power.
Ground is also on a different pin so you can’t just move pins around in software.

The only options are a completely new design or a small adapter board between the computer and nunchuk and an external power supply

gooner2077, 2019-07-01:
Good point

djtulan, 2019-07-02:
@gooner2077 What joystick adapter do you use for your Sinclair? Don't know what the +3 exactly is?

gooner2077, 2019-07-02:
On the zx spectrum +3 128k has 2 Sinclair ports on the side already built-in.

djtulan, 2019-07-02:
@gooner2077 The +5V are not available on the Sinclair Joystick ports it seems.
This adapter cable would also not work:
https://coolnovelties.co.uk/coolnovelties/sinclair-zx-spectrum/90-sinclair-spectrum-128-joystick-adapter-2-port-version-0705693505084.html

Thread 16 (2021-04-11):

Original WII Nunchuck not working

ovesennet, 2021-04-11:
Hi, I just built the nunchuk64, and it is working great with a SNES Mini controller.
However, I cannot get it working with an original WII Nunchuck that I have.
I just checked, it is working in the WII. What can I check?

Firmware 1.2.0

djtulan, 2021-04-12:
Unfortunately, there are two different Nunchuk controllers for the WII. The original model and a newer model. The newer model unfortunately does not work on the Nunchuk64 because the microcontroller is too slow for it. It needs faster i2c polling. But most of the replicas work.

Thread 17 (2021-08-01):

Atmega328PB issues

mamejay, 2021-08-01:
Hi There,
I made a batch of boards using Atmega328PB instead of the Atmega328P.
I have found that they work initially and then stop work working and I see the led dimly flash every second or so.
Sometimes I can start the C64 and it works again.
I replaced with a Atmega328P and all is good again.  Checking and they are supposed to be compatible but wondering if you have any experience with these?
I am wondering if it has something to do with new features of the PB model like the Clock Failure Detection.

https://www.pololu.com/file/0J1464/Atmel-42559-Differences-between-ATmega328P-and-ATmega328PB_ApplicationNote_AT15007.pdf

Anyway let me know what you think.
Thanks

penfold42, 2021-08-15:
Couple of theories.
What fuse settings are you using ?
I wonder what it does if you ask for the full swing oscillator:
https://hackaday.com/2016/05/03/atmel-removes-full-swing-crystal-oscillator/

maybe something is erroneously setting portE to output and the PE0/1 pins that are probably strapped to VCC and GND are having a hard time

mamejay, 2021-08-17:
@penfold42 currently just using default settings as not adding any fuses as per the devs noted.
avrdude -c arduino -P com5 -p m328pb -b 19200 -v -v -U flash:w:nunchuk64.hex
I am hopeless with this stuff.  If you have a suggestion I will try it out.

djtulan, 2021-08-17:
I think, as penfold42 wrote, it has to do with the different pins, which are connected to VCC and GND.
The pdf says the Atmega328PB is NOT a drop in replacement.
What would probably work is a pin compatible controller with less flash memory. Because the firmware doesn't need so much flash.

mamejay, 2021-08-17:
Could you lift those pins that are supposed to be signals and have them floating instead of being connected to VCC or GND?

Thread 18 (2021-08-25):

Problem wit communicating with Nes mini clone controller

Johnlon, 2021-08-25:
Apologie for posting this as an issue - not sure how to get in touch with folk who understand the protocol.

I'm finding that I cannot get a valid response from the controller until I have called decrypt and then init on it.
My controller is a cheap gamepad clone from eBay.

I can see that the nuncheck source code in controller.c get_id()  seems to be reading the controller device id before doing anything else and then using that response to decide whether the init and or decrypt should be called and n what order.

However, with my controller I cannot successfully get the device id until I've already decrypted and init'd the controller.
Up until I have decrypted and init'd the controller I just get 0xFF as the device id.
This means the nuncheck64 takes be down the device unknown branch.

However if I do exactly the sequence   decrypt/init/getid then I get back  0x01 | 0x00 | 0xA4 | 0x20 | 0x03 | 0x01

This result is similar to the one you have for ID_NES_Classic_Mini_Clone_Encrypted however byte[4] is is 0x03 in my case rather than what you have 0x00 because my init code is requesting data format 3 and not data format 0.

Data format 0 is not available on my controller and it only respond with 8 bytes (ie format 3) and not 6 bytes so rather than doing an init requesting format 0 I'm requesting format 3. BTW If I request format 0 it still respond with format 3 regardess.

In anycase it seems the logic in nunchuck 64 doesn't work for my clone and the only order that works is ..  decrypt/init and then getid or read state work fine.

Is this a known issue with some controllers?

Is there a forum where this would be better asked?

Thanks

avongil, 2022-12-21:
Have you figured this problem out? I am having issues connecting my SNES wireless clone also.  Any insight would be great.

Johnlon, 2022-12-21:
Yes  got it working with cloned i2c controllers off eBay....

https://hackaday.io/project/181036-nes-controller-interface-using-pic16f18446

All code is in GitHub including notes....

https://github.com/Johnlon/NESInterfaceAndPeripherals/blob/main/README.md

Hope that helps

John

Johnlon, 2022-12-21:
Ah yours are wireless.
Mine are wired i2c

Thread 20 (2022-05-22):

errors in layout in the nunchuk throughhole version

bwack, 2022-05-22:
Hi. I got a message saying that there is something wrong with the gerbers of the throughhole version.
I know why this has happened. After testing the prototype, I decided to change the footprints of Q1-Q4.
That resulted in some shorted traces. I ran the DRC, and no errors show up. That is a bug in kicad!

I will create a pull request with the fixes :)

Closed 2024-02-29.

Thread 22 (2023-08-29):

No input from controllers

rmdesign, 2023-08-29:
I purchased these controllers to work with the Nunchuk64: https://www.kogan.com/au/buy/supperstore-rechargeable-wireless-controller-for-snessfc-classic-edition-multi-button-sre-bf0296-multi_button/

They pair with their receivers, but the C64 doesn't receive any input from the controllers.

rmdesign, 2023-09-05:
Looks like these controllers are incompatible. My Nunchuk64 works fine with a wired Wii Nunchuk.

Closed 2023-09-05.

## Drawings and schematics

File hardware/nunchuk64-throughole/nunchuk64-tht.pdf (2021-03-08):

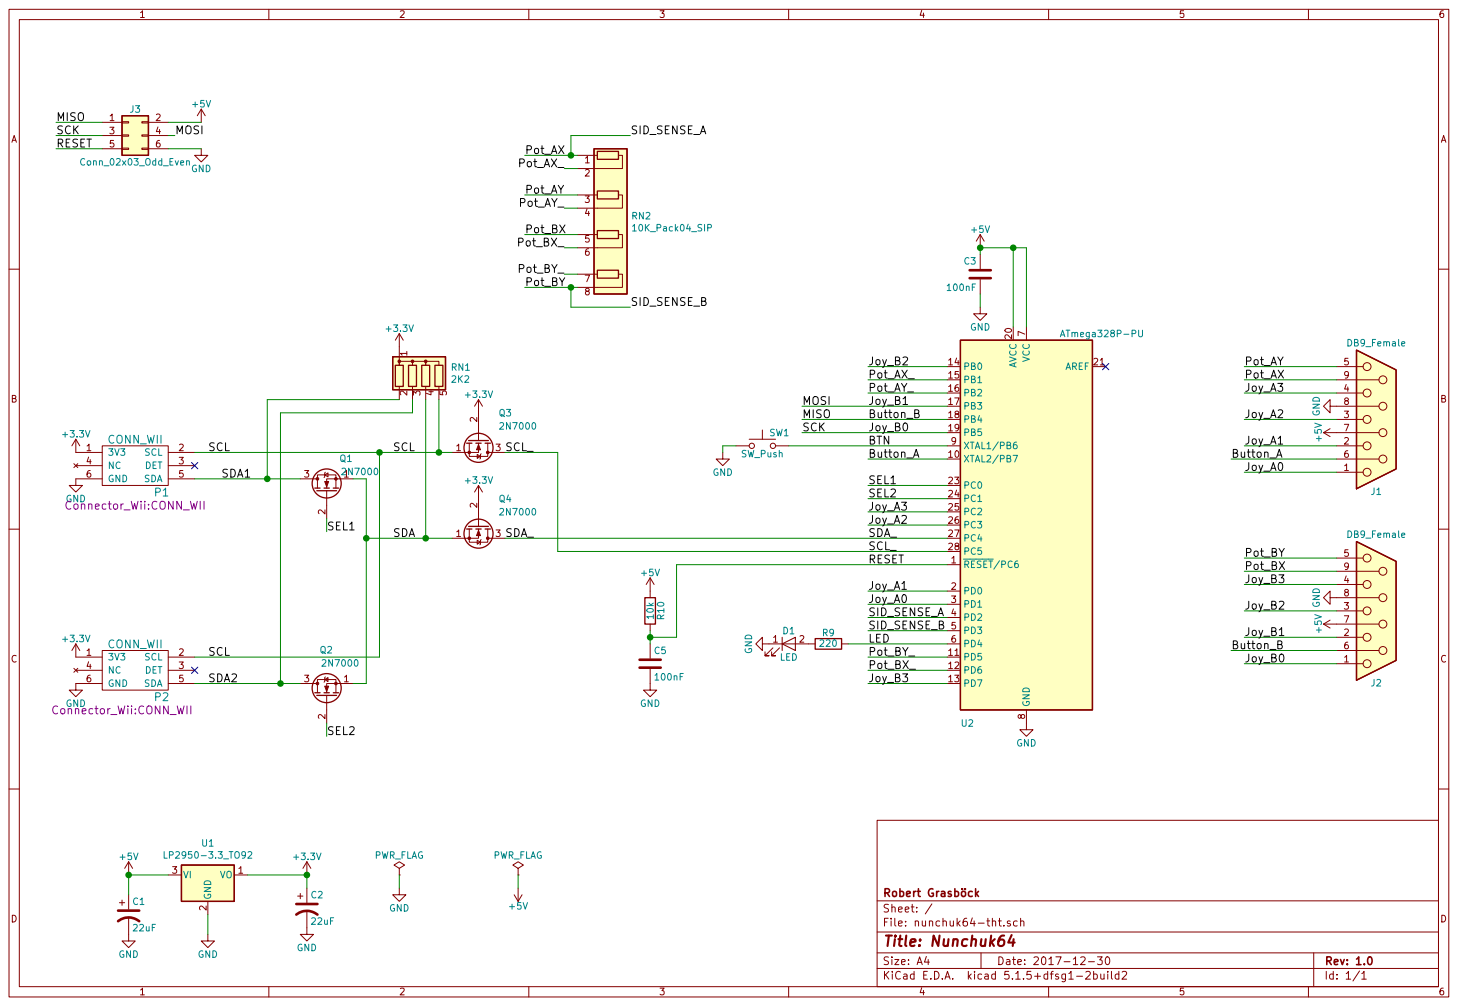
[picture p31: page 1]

File: nunchuk64-tht.sch Sheet: / Robert Grasböck 10k R10

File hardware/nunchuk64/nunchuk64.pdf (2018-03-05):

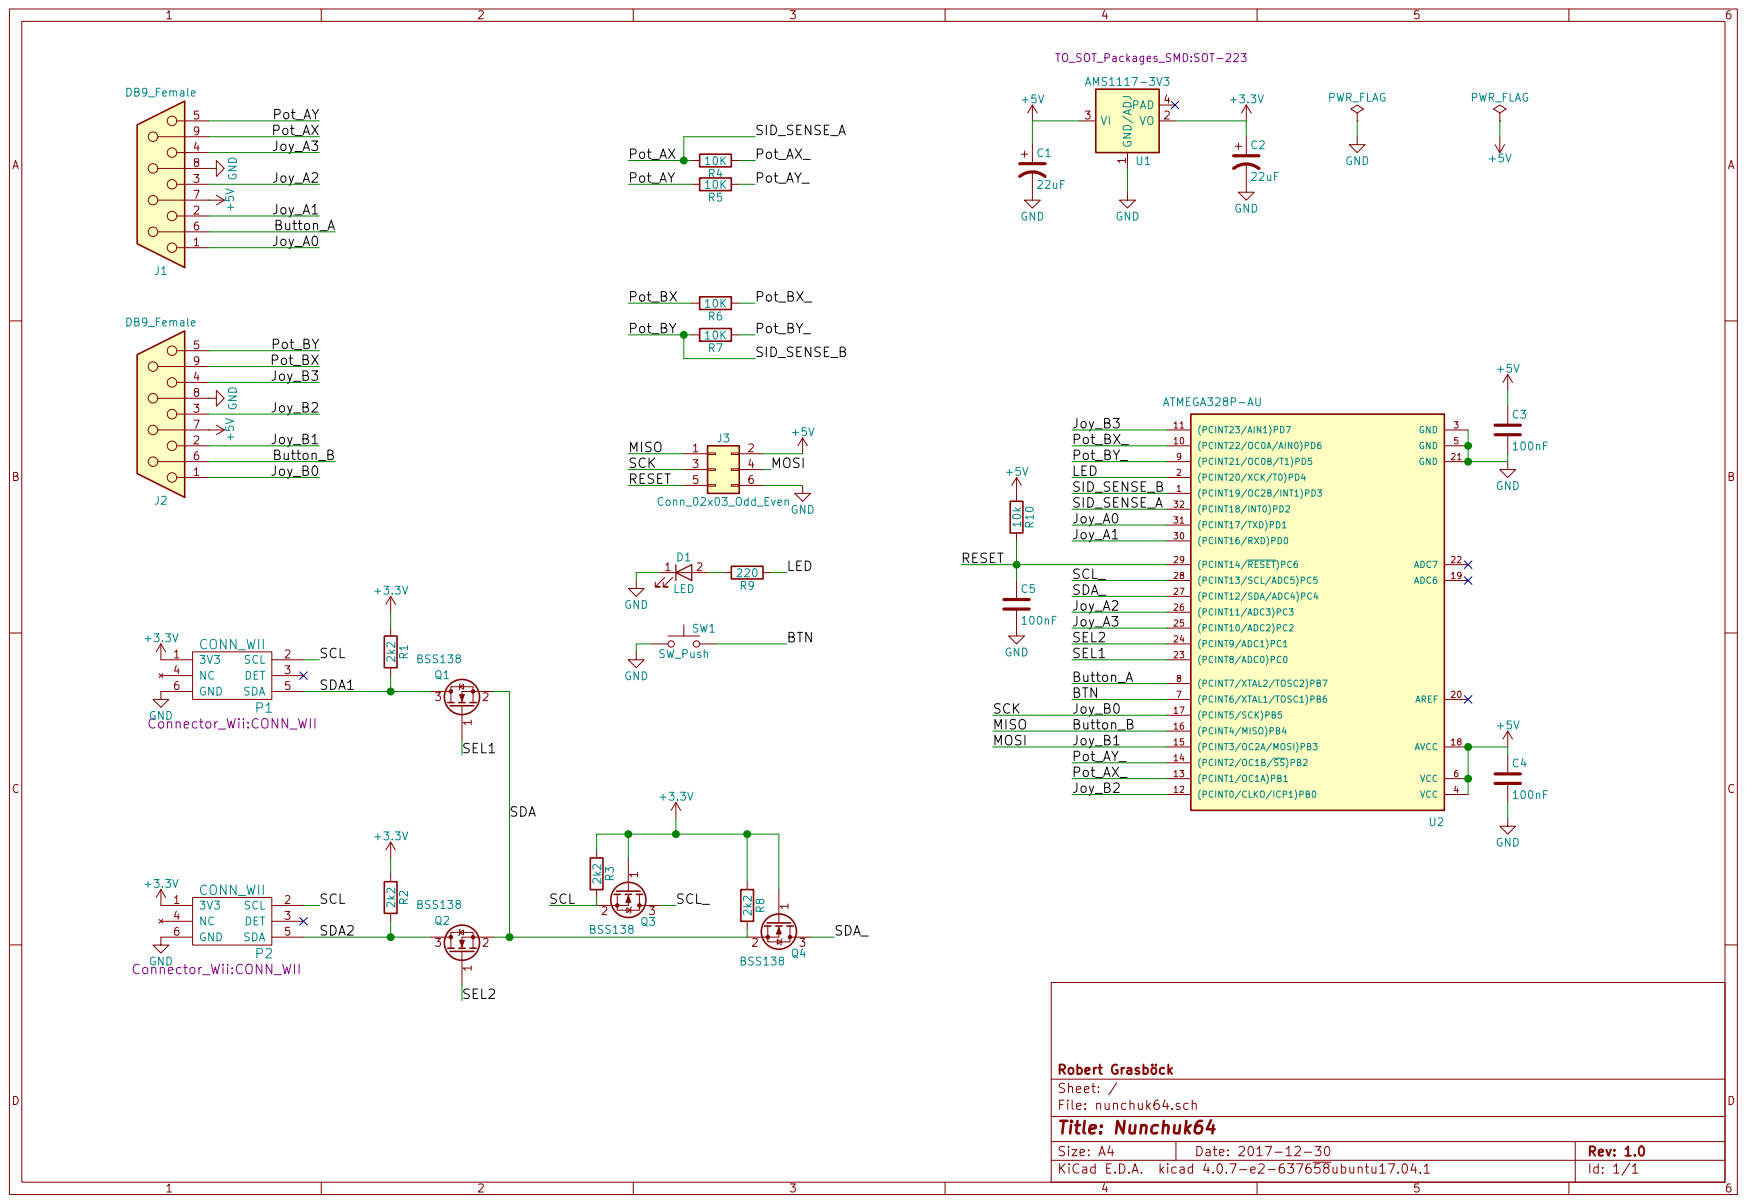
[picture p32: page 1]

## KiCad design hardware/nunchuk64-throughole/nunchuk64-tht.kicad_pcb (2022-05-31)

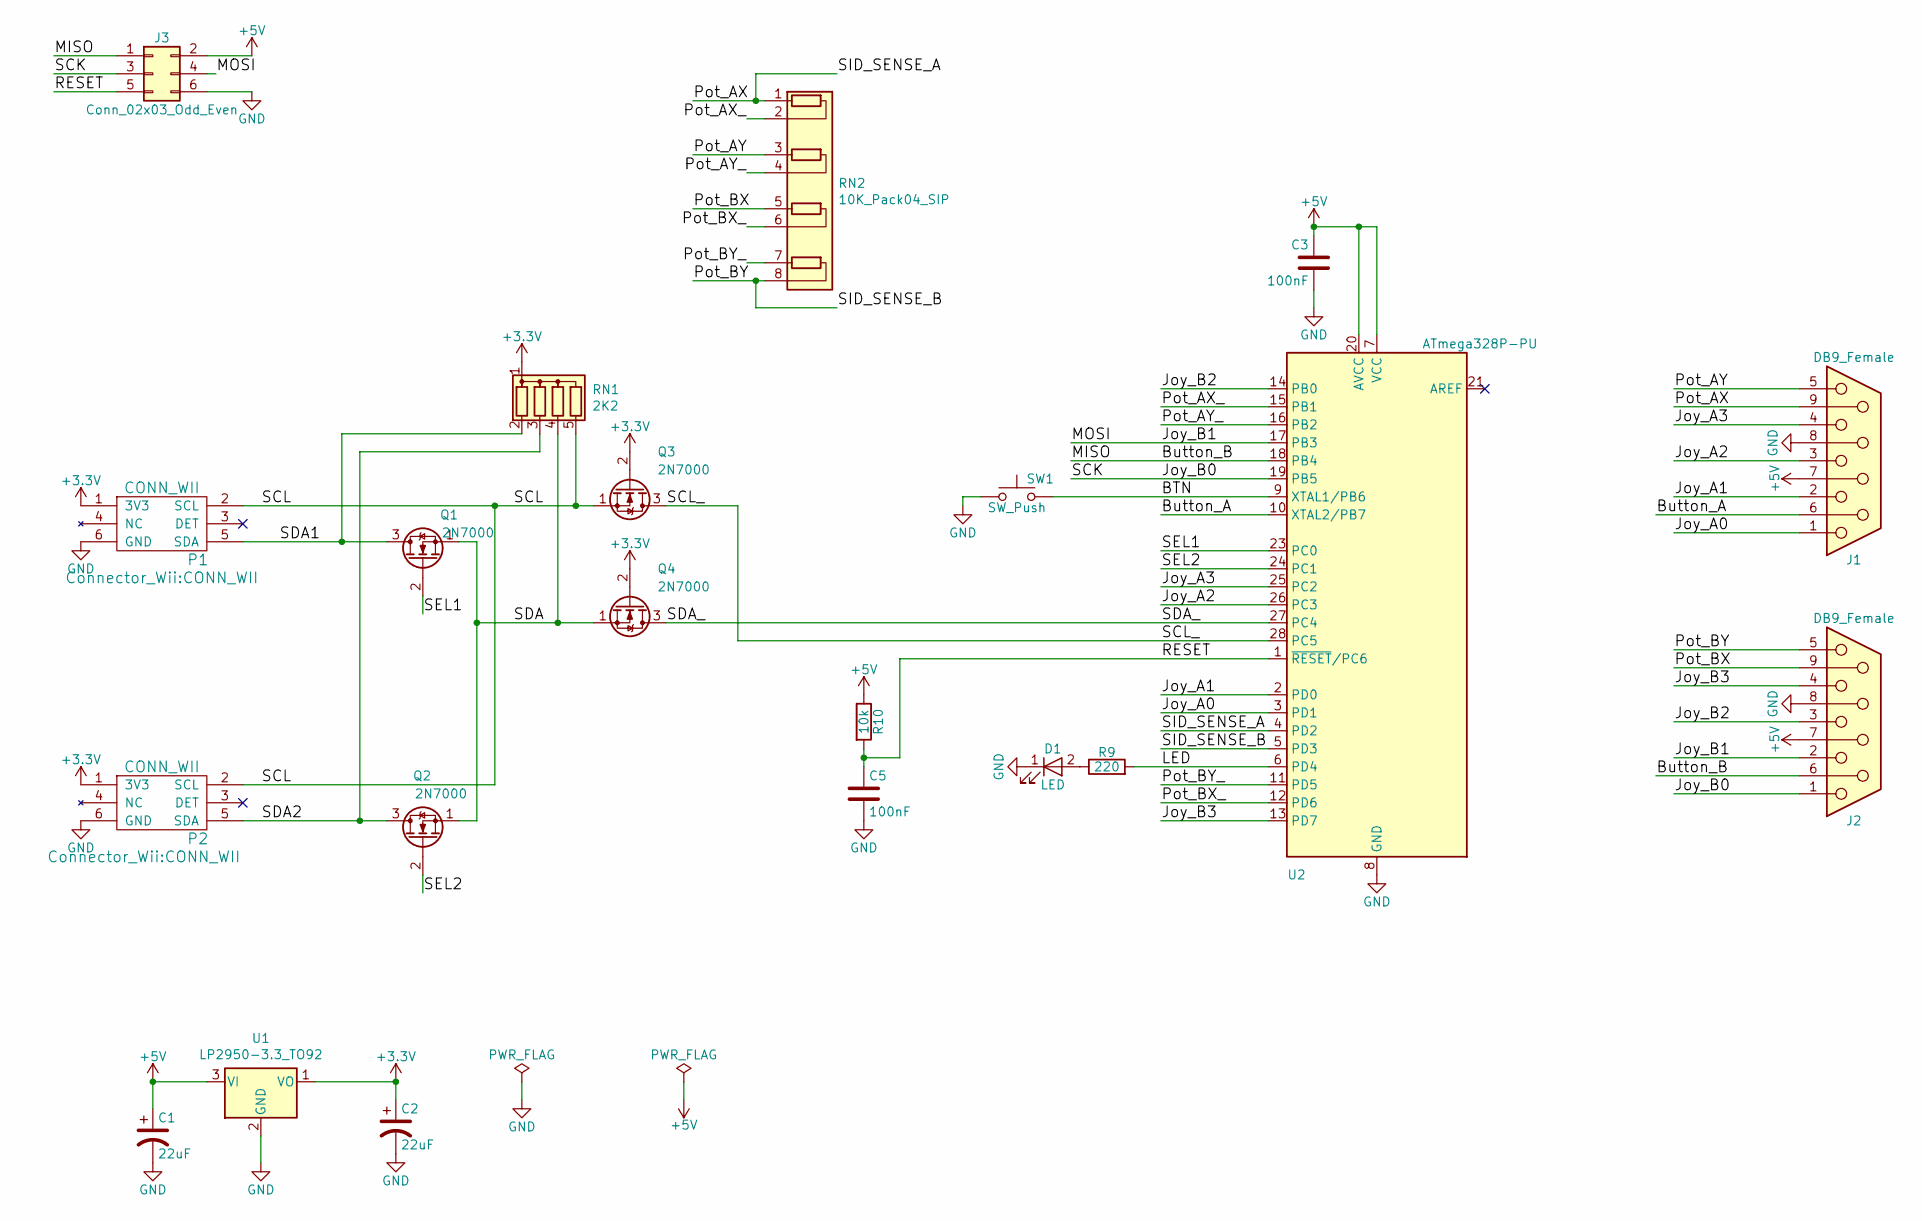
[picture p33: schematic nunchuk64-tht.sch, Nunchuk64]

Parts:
C1, C2: 22uF; CP_Radial_D5.0mm_P2.50mm
C3, C5: 100nF; C_Disc_D5.0mm_W2.5mm_P5.00mm
D1: LED; LED_D3.0mm
J1, J2: DB9_Female; DSUB-9_Female_EdgeMount_Pitch2.77mm
J3: Conn_02x03_Odd_Even; AVR-ISP-6-TH
P1, P2: CONN_WII
Q1, Q2, Q3, Q4: 2N7000; TO-92_Inline
R9: 220; R_Axial_DIN0207_L6.3mm_D2.5mm_P7.62mm_Horizontal
R10: 10k; R_Axial_DIN0207_L6.3mm_D2.5mm_P7.62mm_Horizontal
RN1: 2K2; R_Array_SIP5
RN2: 10K_Pack04_SIP; R_Array_SIP8
SW1: SW_Push; SW_PUSH_6mm_h13mm
U1: LP2950-3.3_TO92; TO-92_Inline_Wide
U2: ATmega328P-PU; DIP-28_W7.62mm

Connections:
+3V3: C2.1, P1.1 (3V3), P2.1 (3V3), Q3.2 (G), Q4.2 (G), RN1.1 (common), U1.1 (VO)
+5V: C1.1, C3.1, J1.7, J2.7, J3.2, R10.1, U1.3 (VI), U2.7 (VCC), U2.20 (AVCC)
/BTN: SW1.2, U2.9 (XTAL1/PB6)
/Button_A: J1.6, U2.10 (XTAL2/PB7)
/Button_B: J2.6, J3.1, U2.18 (PB4)
/Joy_A0: J1.1, U2.3 (PD1)
/Joy_A1: J1.2, U2.2 (PD0)
/Joy_A2: J1.3, U2.26 (PC3)
/Joy_A3: J1.4, U2.25 (PC2)
/Joy_B0: J2.1, J3.3, U2.19 (PB5)
/Joy_B1: J2.2, J3.4, U2.17 (PB3)
/Joy_B2: J2.3, U2.14 (PB0)
/Joy_B3: J2.4, U2.13 (PD7)
/LED: R9.2, U2.6 (PD4)
/Pot_AX: J1.9, RN2.1 (R1.1), U2.4 (PD2)
/Pot_AX_: RN2.2 (R1.2), U2.15 (PB1)
/Pot_AY: J1.5, RN2.3 (R2.1)
/Pot_AY_: RN2.4 (R2.2), U2.16 (PB2)
/Pot_BX: J2.9, RN2.5 (R3.1)
/Pot_BX_: RN2.6 (R3.2), U2.12 (PD6)
/Pot_BY: J2.5, RN2.8 (R4.2), U2.5 (PD3)
/Pot_BY_: RN2.7 (R4.1), U2.11 (PD5)
/RESET: C5.1, J3.5, R10.2, U2.1 (~RESET~/PC6)
/SCL: P1.2 (SCL), P2.2 (SCL), Q3.1 (S), RN1.5 (R4)
/SCL_: Q3.3 (D), U2.28 (PC5)
/SDA: Q1.1 (S), Q2.1 (S), Q4.1 (S), RN1.4 (R3)
/SDA1: P1.5 (SDA), Q1.3 (D), RN1.2 (R1)
/SDA2: P2.5 (SDA), Q2.3 (D), RN1.3 (R2)
/SDA_: Q4.3 (D), U2.27 (PC4)
/SEL1: Q1.2 (G), U2.23 (PC0)
/SEL2: Q2.2 (G), U2.24 (PC1)
GND: C1.2, C2.2, C3.2, C5.2, D1.1 (K), J1.8, J2.8, J3.6, P1.6 (GND), P2.6 (GND), SW1.1, U1.2 (GND), U2.8 (GND), U2.22 (GND)
unnamed: D1.2 (A), R9.1

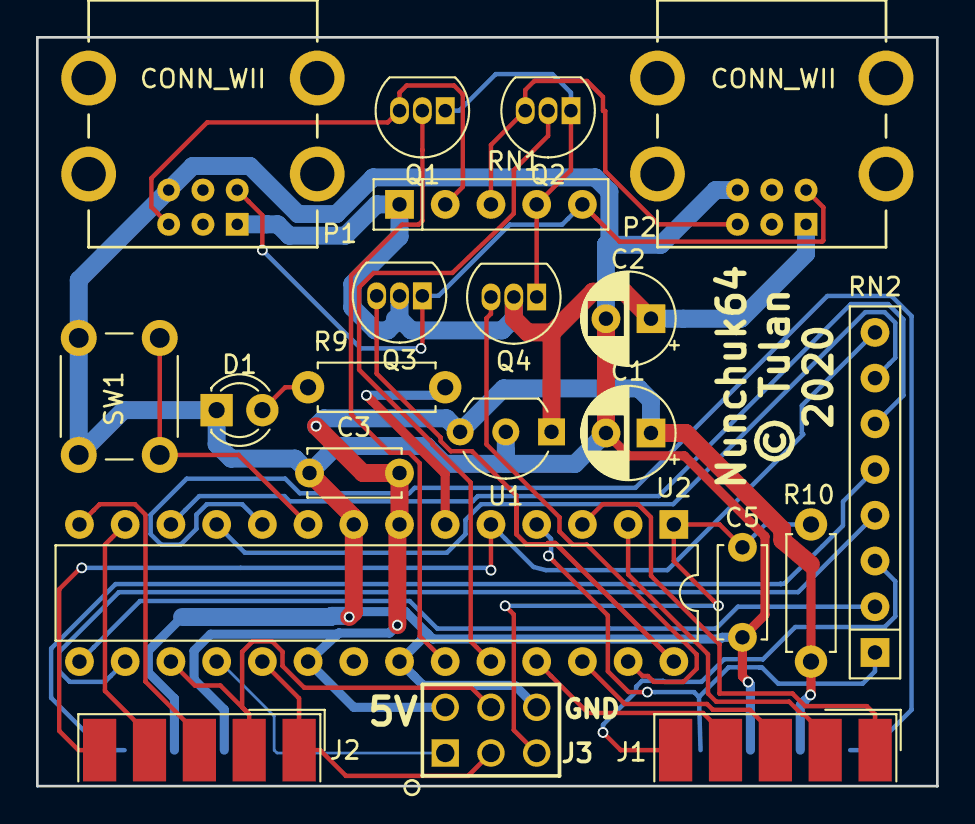
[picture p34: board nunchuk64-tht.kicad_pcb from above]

Board: 2 copper layers, 50.0 x 41.6 mm, 21 parts (0 on the bottom side), 33 nets.

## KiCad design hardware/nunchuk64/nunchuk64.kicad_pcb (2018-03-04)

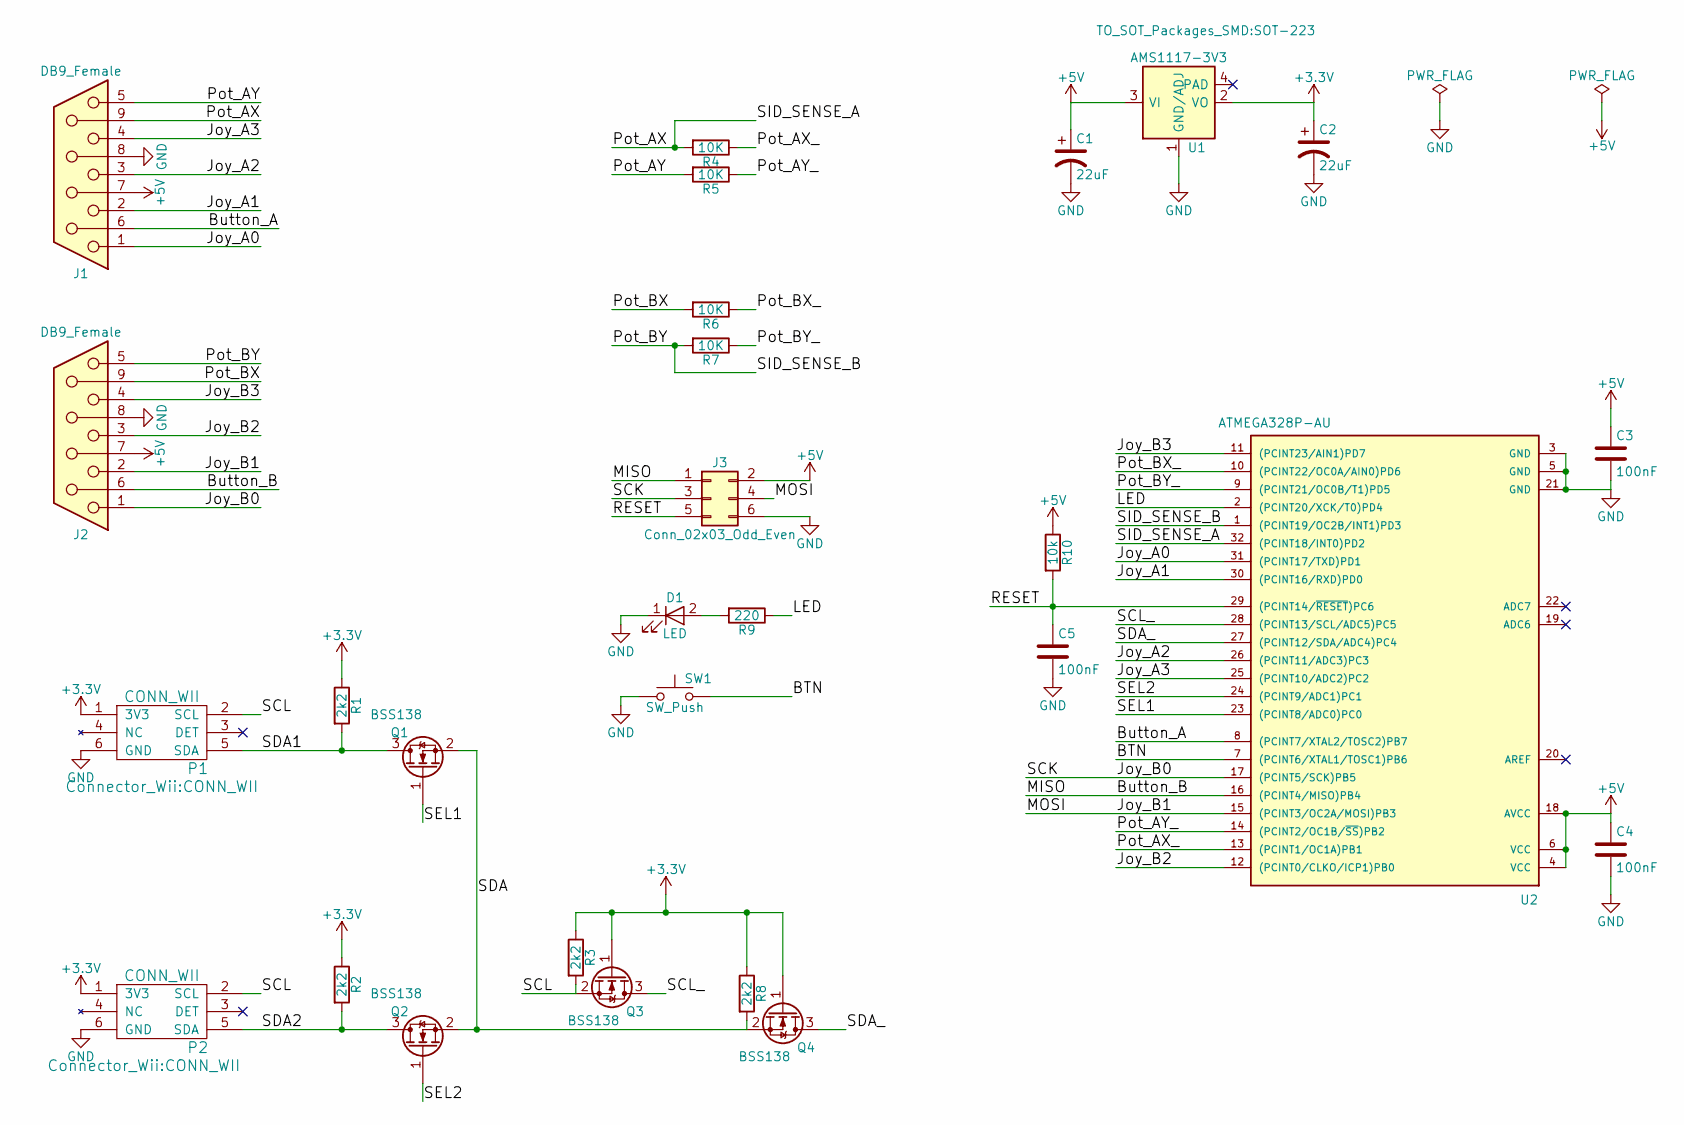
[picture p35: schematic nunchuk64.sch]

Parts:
C1, C2: 22uF; CP_Tantalum_Case-A_EIA-3216-18_Hand
C3, C4, C5: 100nF; C_0805_HandSoldering
D1: LED; LED_1206_HandSoldering
J1, J2: DB9_Female; DSUB-9_Female_EdgeMount_Pitch2.77mm
J3: Conn_02x03_Odd_Even; AVR-ISP-6-TH
P1, P2: CONN_WII
Q1, Q2, Q3, Q4: BSS138; SOT-23_Handsoldering
R1, R2, R3, R8: 2k2; R_0805_HandSoldering
R4, R5, R6, R7: 10K; R_0805_HandSoldering
R9: 220; R_0805_HandSoldering
R10: 10k; R_0805_HandSoldering
SW1: SW_Push; SW_PUSH_6mm_h13mm
U1: AMS1117-3V3; SOT-223; MPN LM1117
U2: ATMEGA328P-AU; TQFP-32_7x7mm_Pitch0.8mm

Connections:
+3V3: C2.1, P1.1 (3V3), P2.1 (3V3), Q3.1 (G), Q4.1 (G), R1.1, R2.1, R3.1, R8.1, U1.2 (VO)
+5V: C1.1, C3.1, C4.1, J1.7, J2.7, J3.2, R10.1, U1.3 (VI), U2.4 (VCC), U2.6 (VCC), U2.18 (AVCC)
/BTN: SW1.2, U2.7 ((PCINT6/XTAL1/TOSC1)PB6)
/Button_A: J1.6, U2.8 ((PCINT7/XTAL2/TOSC2)PB7)
/Button_B: J2.6, J3.1, U2.16 ((PCINT4/MISO)PB4)
/Joy_A0: J1.1, U2.31 ((PCINT17/TXD)PD1)
/Joy_A1: J1.2, U2.30 ((PCINT16/RXD)PD0)
/Joy_A2: J1.3, U2.26 ((PCINT11/ADC3)PC3)
/Joy_A3: J1.4, U2.25 ((PCINT10/ADC2)PC2)
/Joy_B0: J2.1, J3.3, U2.17 ((PCINT5/SCK)PB5)
/Joy_B1: J2.2, J3.4, U2.15 ((PCINT3/OC2A/MOSI)PB3)
/Joy_B2: J2.3, U2.12 ((PCINT0/CLKO/ICP1)PB0)
/Joy_B3: J2.4, U2.11 ((PCINT23/AIN1)PD7)
/LED: R9.1, U2.2 ((PCINT20/XCK/T0)PD4)
/Pot_AX: J1.9, R4.2, U2.32 ((PCINT18/INT0)PD2)
/Pot_AX_: R4.1, U2.13 ((PCINT1/OC1A)PB1)
/Pot_AY: J1.5, R5.2
/Pot_AY_: R5.1, U2.14 ((PCINT2/OC1B/~SS~)PB2)
/Pot_BX: J2.9, R6.2
/Pot_BX_: R6.1, U2.10 ((PCINT22/OC0A/AIN0)PD6)
/Pot_BY: J2.5, R7.2, U2.1 ((PCINT19/OC2B/INT1)PD3)
/Pot_BY_: R7.1, U2.9 ((PCINT21/OC0B/T1)PD5)
/RESET: C5.1, J3.5, R10.2, U2.29 ((PCINT14/~RESET~)PC6)
/SCL: P1.2 (SCL), P2.2 (SCL), Q3.2 (S), R3.2
/SCL_: Q3.3 (D), U2.28 ((PCINT13/SCL/ADC5)PC5)
/SDA: Q1.2 (S), Q2.2 (S), Q4.2 (S), R8.2
/SDA1: P1.5 (SDA), Q1.3 (D), R1.2
/SDA2: P2.5 (SDA), Q2.3 (D), R2.2
/SDA_: Q4.3 (D), U2.27 ((PCINT12/SDA/ADC4)PC4)
/SEL1: Q1.1 (G), U2.23 ((PCINT8/ADC0)PC0)
/SEL2: Q2.1 (G), U2.24 ((PCINT9/ADC1)PC1)
GND: C1.2, C2.2, C3.2, C4.2, C5.2, D1.1 (K), J1.8, J2.8, J3.6, P1.6 (GND), P2.6 (GND), SW1.1, U1.1 (GND/ADJ), U2.3 (GND), U2.5 (GND), U2.21 (GND)
unnamed: D1.2 (A), R9.2

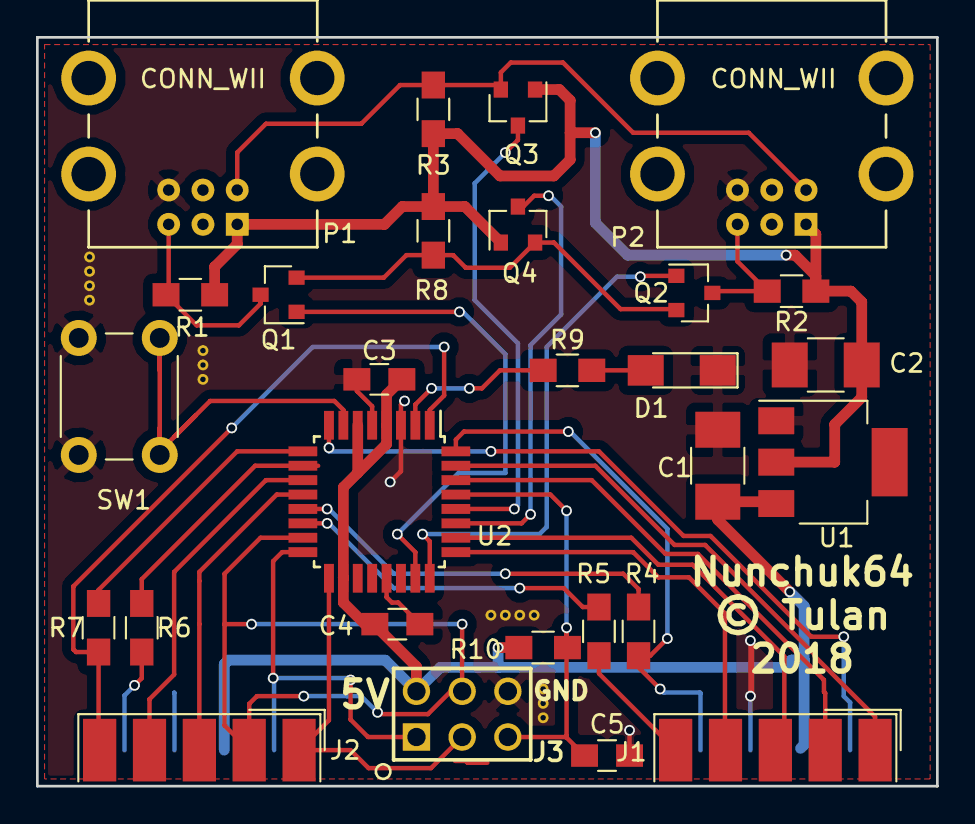
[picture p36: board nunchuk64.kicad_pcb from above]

Board: 2 copper layers, 50.0 x 41.6 mm, 28 parts (0 on the bottom side), 33 nets.

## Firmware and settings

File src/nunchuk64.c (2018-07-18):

//=============================================================================
// *** Nunchuk64 ***
// Copyright (c) Robert Grasböck, All rights reserved.
//
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
// You should have received a copy of the GNU General Public License
// along with this program.  If not, see <http://www.gnu.org/licenses/>.
//=============================================================================
/// @file   nunchuk64.c
/// @author Robert Grasböck (robert.grasboeck@gmail.com)
/// @date   December, 2017
/// @brief  main
//=============================================================================
#include <inttypes.h>
#include <stdio.h>

#include <avr/interrupt.h>
#include <avr/wdt.h>
// #include <util/delay.h>

#include "led.h"
#include "button.h"
#include "i2c_master.h"
#include "ioconfig.h"
#include "enums.h"
#include "selector.h"
#include "controller.h"
#include "joystick.h"
#include "paddle.h"
#include "timer.h"

// drivers
#include "driver_nes_classic.h"
#include "driver_nunchuk.h"
#include "driver_wii_classic.h"

static volatile Driver *driver[NUMBER_PORTS] = {NULL, NULL};
static volatile uint8_t ext[NUMBER_PORTS] = {1, 1};

static Driver *GetDriver(ControllerID id) {
  switch (id) {
    case ID_Nunchuck:
      return &drv_nunchuk;

    case ID_Wii_Classic:
    case ID_Wii_Classic_Pro:
    case ID_NES_Classic_Mini_Clone_Encrypted:
    case ID_8Bitdo_SF30:
      return &drv_wii_classic;

    case MAX_IDs:
    case ID_Unknown:
      return NULL;
  }

  return NULL;
}

static void init(void) {
  // ===================================
  // init modules
  // ===================================
  led_init();         // init led output
  led_switch(LED_ON); // diagnose (in init)

  button_init();      // init button input
  selector_init();    // init i2c bus selector
  i2c_init();         // init i2c routines
  joystick_init();    // init joystick outputs
  paddle_init();      // init paddle outputs
  timer_init();       // init timer interrupt

  // ===================================
  // enable watchdog, woof
  // ===================================
  wdt_enable(WDTO_1S);

  // ===================================
  // enable interrupts
  // ===================================
  sei();

  led_switch(LED_OFF); // diagnose (in init)
}

static Port switch_port(Port p) {
  if (p == PORT_A)
    return PORT_B;
  else
    return PORT_A;
}

static void handle_paddle_enabled(uint8_t switched_ports) {
  for (Port p = PORT_A; p <= PORT_B; p++) {

    Port setport = p;

    if (switched_ports == TRUE) {
      setport = switch_port(setport);
    }

    if (driver[p] != NULL && driver[p]->get_paddle_enabled() == TRUE) {
      ext[p] = 0;
      paddle_start(setport);
    } else {
      paddle_stop(setport);
      ext[p] = 1;
    }
  }
}

int main(void) {
  // ===================================
  // init everything
  // ===================================
  init();


  ContollerData cd[NUMBER_PORTS];  // controller data
  Joystick joystick[NUMBER_PORTS] = {0, 0}; // joystick data
  Paddle paddle[NUMBER_PORTS] = {{0, 0}, {0, 0}}; // joystick data
  uint8_t switched_ports = FALSE;

  // ===================================
  // MAIN LOOP
  while (1) {

    // ================
    // calm watchdog down
    // ================
    wdt_reset();

    // ================
    // read button
    // ================
    button_debounce();

    // short press
    if (button_get() == TRUE) {
      // set to next led state
      led_setnextstate();

      handle_paddle_enabled(switched_ports); // handle paddle enabled
    }

    // long press
    if (button_get_long() == TRUE) {
      switched_ports = (switched_ports == FALSE) ? TRUE : FALSE;

      handle_paddle_enabled(switched_ports); // handle paddle disabled

      led_quick_blink(switched_ports ? 2 : 1);
    }

    // ===================================
    // communiate with controllers
    // ===================================
    for (uint8_t p = PORT_A; p <= PORT_B; p++) {
      // select I2C port
      selector_switch(p);
      // _delay_ms(1);

      // ===================================
      // detect controller type, set driver
      // ===================================
      if (driver[p] == NULL) {
        driver[p] = GetDriver(get_id());

        // new driver found
        if (driver[p] != NULL) {
          handle_paddle_enabled(switched_ports);
        }

        // ===================================
        // read data from controller
        // ===================================
      } else {
        // controller read failed? -> delete driver
        if (controller_read(&cd[p]) == FALSE) {
          driver[p] = NULL;
          joystick[p] = 0; // delete old data
          handle_paddle_enabled(switched_ports);
        }
      }

      // translate the controller date to joystick data
      if (driver[p] != NULL) {
        driver[p]->get_joystick_state(&cd[p], &joystick[p]);
        driver[p]->get_paddle_state(&cd[p], &paddle[p]);
      }
    }

    // switched mode?
    if (switched_ports == FALSE) {

      joystick_update(joystick[PORT_A], ext[PORT_A], joystick[PORT_B], ext[PORT_B]);
      paddle_update(&paddle[PORT_A], &paddle[PORT_B]);
    } else {
      joystick_update(joystick[PORT_B], ext[PORT_B], joystick[PORT_A], ext[PORT_A]);
      paddle_update(&paddle[PORT_B], &paddle[PORT_A]);
    }
  }

  //  MAIN LOOP
  // ===================================

  return 0;
}

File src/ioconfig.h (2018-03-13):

//=============================================================================
// *** Nunchuk64 ***
// Copyright (c) Robert Grasböck, All rights reserved.
//
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
// You should have received a copy of the GNU General Public License
// along with this program.  If not, see <http://www.gnu.org/licenses/>.
//=============================================================================
/// @file   ioconfig.h
/// @author Robert Grasböck (robert.grasboeck@gmail.com)
/// @date   December, 2017
/// @brief  io pin configuration
//=============================================================================
#ifndef _IOCONFIG_H_
#define _IOCONFIG_H_

#include <avr/io.h>

#define BIT_GET(ADR,BIT)   ((ADR) & (_BV(BIT)))
#define BIT_SET(ADR,BIT)   ((ADR) |= (_BV(BIT)))
#define BIT_CLEAR(ADR,BIT) ((ADR) &= ~(_BV(BIT)))
#define BIT_FLIP(ADR,BIT)  ((ADR) ^= (_BV(BIT)))

// ========================================================
//  LED
// ========================================================

// led port, ddr and bit
#define PORT_LED           PORTD // PD4
#define DDR_LED             DDRD // PD4
#define BIT_LED                4 // PD4

// ========================================================
//  BUTTON
// ========================================================

// button port, ddr and bit
#define PIN_BUTTON          PINB // PB6
#define PORT_BUTTON        PORTB // PB6
#define DDR_BUTTON          DDRB // PB6
#define BIT_BUTTON             6 // PB6

// ========================================================
//  I2C Select
// ========================================================

// select1 port, ddr and bit
#define PORT_SEL1          PORTC // PC0
#define DDR_SEL1            DDRC // PC0
#define BIT_SEL1               0 // PC0

// select2 port, ddr and bit
#define PORT_SEL2          PORTC // PC1
#define DDR_SEL2            DDRC // PC1
#define BIT_SEL2               1 // PC1

// ========================================================
//  DIGITAL JOYSTICK OUTPUTS
// ========================================================

// io register for joystick outputs
#define PORT_JOY_A0        PORTD // PD1
#define PORT_JOY_A1        PORTD // PD0
#define PORT_JOY_A2        PORTC // PC3
#define PORT_JOY_A3        PORTC // PC2
#define PORT_BUTTON_A      PORTB // PB7
#define PORT_BUTTON2_A     PORTB // PB1
#define PORT_BUTTON3_A     PORTB // PB2 
#define PORT_JOY_B0        PORTB // PB5
#define PORT_JOY_B1        PORTB // PB3
#define PORT_JOY_B2        PORTB // PB0
#define PORT_JOY_B3        PORTD // PD7
#define PORT_BUTTON_B      PORTB // PB4
#define PORT_BUTTON2_B     PORTD // PD5
#define PORT_BUTTON3_B     PORTD // PD6


// ddr for joystick outputs
#define DDR_JOY_A0          DDRD // PD1
#define DDR_JOY_A1          DDRD // PD0
#define DDR_JOY_A2          DDRC // PC3
#define DDR_JOY_A3          DDRC // PC2
#define DDR_BUTTON_A        DDRB // PB7
#define DDR_BUTTON2_A       DDRB // PB1
#define DDR_BUTTON3_A       DDRB // PB2
#define DDR_JOY_B0          DDRB // PB5
#define DDR_JOY_B1          DDRB // PB3
#define DDR_JOY_B2          DDRB // PB0
#define DDR_JOY_B3          DDRD // PD7
#define DDR_BUTTON_B        DDRB // PB4
#define DDR_BUTTON2_B       DDRD // PD6
#define DDR_BUTTON3_B       DDRD // PD5

// bits for joystick outputs
#define BIT_JOY_A0             1 // PD1
#define BIT_JOY_A1             0 // PD0
#define BIT_JOY_A2             3 // PC3
#define BIT_JOY_A3             2 // PC2
#define BIT_BUTTON_A           7 // PB7
#define BIT_BUTTON2_A          1 // PB1
#define BIT_BUTTON3_A          2 // PB2
#define BIT_JOY_B0             5 // PB5
#define BIT_JOY_B1             3 // PB3
#define BIT_JOY_B2             0 // PB0
#define BIT_JOY_B3             7 // PD7
#define BIT_BUTTON_B           4 // PB4
#define BIT_BUTTON2_B          6 // PD6
#define BIT_BUTTON3_B          5 // PD5

// ========================================================
//  PADDLE INPUTS & OUTPUTS
// ========================================================

// io register for paddle inputs / outputs
#define PORT_SENSE_A       PORTD // PD2
#define PORT_PADDLE_A_X    PORTB // PB1
#define PORT_PADDLE_A_Y    PORTB // PB2

#define PORT_SENSE_B       PORTD // PD3
#define PORT_PADDLE_B_Y    PORTD // PD5
#define PORT_PADDLE_B_X    PORTD // PD6

// ddr for paddle inputs / outputs
#define DDR_SENSE_A         DDRD // PD2
#define DDR_PADDLE_A_X      DDRB // PB1
#define DDR_PADDLE_A_Y      DDRB // PB2

#define DDR_SENSE_B         DDRD // PD3
#define DDR_PADDLE_B_X      DDRD // PD6
#define DDR_PADDLE_B_Y      DDRD // PD5

// bits for paddle sense
#define BIT_SENSE_A            2 // PD2
#define BIT_PADDLE_A_X         1 // PB1
#define BIT_PADDLE_A_Y         2 // PB2

#define BIT_SENSE_B            3 // PD3
#define BIT_PADDLE_B_X         6 // PD6
#define BIT_PADDLE_B_Y         5 // PD5

#endif

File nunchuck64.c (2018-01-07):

//=============================================================================
// *** Nunchuk64 ***
// Copyright (c) Robert Grasböck, All rights reserved.
//
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
// You should have received a copy of the GNU General Public License
// along with this program.  If not, see <http://www.gnu.org/licenses/>.
//=============================================================================
/// @file   nunchuck64.c
/// @author Robert Grasböck (robert.grasboeck@gmail.com)
/// @date   December, 2017
/// @brief  main
//=============================================================================
#include <inttypes.h>
#include <stdio.h>
#include <stdlib.h>

#include <avr/io.h>
#include <avr/interrupt.h>
#include <util/delay.h>

#include "i2c_master.h"
#include "ioconfig.h"
#include "controller.h"
#include "joystick.h"
#include "paddle.h"

void init_select(void) {
  DDR_SEL1 |= _BV(BIT_SEL1);    // enable output
  DDR_SEL2 |= _BV(BIT_SEL2);    // enable output

  PORT_SEL1 &= ~_BV(BIT_SEL1);  // set to 0 (selected)
  PORT_SEL2 &= ~_BV(BIT_SEL2);  // set to 0 (selected)
}

void switch_select(uint8_t port) {
  if (port == PORT_A) {
    PORT_SEL2 &= ~_BV(BIT_SEL2);  // set to 0 (not selected)
    PORT_SEL1 |= _BV(BIT_SEL1);   // set to 1 (selected)

  } else if (port == PORT_B) {
    PORT_SEL1 &= ~_BV(BIT_SEL1);  // set to 0 (not selected)
    PORT_SEL2 |= _BV(BIT_SEL2);   // set to 1 (selected)
  }
}

void init(void) {
  DDR_LED |= _BV(BIT_LED);      // enable output
  PORT_LED |= _BV(BIT_LED);     // set to 1 => LED ON

  // init modules
  i2c_init();
  init_select();
  joystick_init();
  paddle_init();

  _delay_ms(1);

  // select i2c port A
  switch_select(PORT_A);
  _delay_ms(1);
  controller_init();
  _delay_ms(1);

  // select i2c port B
  switch_select(PORT_B);
  _delay_ms(1);
  controller_init();
  _delay_ms(1);
}

int main(void) {
  init();

  uint8_t port = PORT_A;
  ContollerData cd;

  // MAIN LOOP
  while (1) {

    // select I2C port
    switch_select(port);

    // get data from port
    controller_read(&cd);

    // give data to c64 joystick port
    joystick_poll(&cd, port);

    // toogle port
    port = (port == PORT_A) ? PORT_B : PORT_A;

    /*
        if (cd.byte5 & _BV(6)) {
          PORT_LED |= _BV(BIT_LED);
        } else {
          PORT_LED &= ~_BV(BIT_LED);
          _delay_ms(1);
        }
    */
  }

  return 0;
}

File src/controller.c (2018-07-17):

//=============================================================================
// *** Nunchuk64 ***
// Copyright (c) Robert Grasböck, All rights reserved.
//
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
// You should have received a copy of the GNU General Public License
// along with this program.  If not, see <http://www.gnu.org/licenses/>.
//=============================================================================
/// @file   controller.c
/// @author Robert Grasböck (robert.grasboeck@gmail.com)
/// @date   December, 2017
/// @brief  i2c controller
//=============================================================================
#include <string.h>
#include <avr/pgmspace.h>

// #include <util/delay.h>
#include "ioconfig.h"

#include "enums.h"
#include "i2c_master.h"
#include "controller.h"

#define CONTROLLER_ADDR (0x52<<1) ///< device address

void controller_init(void) {
  // --------------------
  // send 0x55 to register 0xf0
  i2c_start(CONTROLLER_ADDR | I2C_WRITE);
  i2c_write(0xf0);
  i2c_write(0x55);
  i2c_stop();
  // --------------------

  // --------------------
  // send 0x00 to register 0xfb
  i2c_start(CONTROLLER_ADDR | I2C_WRITE);
  i2c_write(0xfb);
  i2c_write(0x00);
  i2c_stop();
  // --------------------

  // --------------------
  // send 0x00 to register 0xfe
  i2c_start(CONTROLLER_ADDR | I2C_WRITE);
  i2c_write(0xfe);
  i2c_write(0x00);
  i2c_stop();
  // --------------------
}

static void controller_disable_encryption(void) {
  // --------------------
  // send 0xaa to register 0xf0
  i2c_start_wait(CONTROLLER_ADDR | I2C_WRITE);
  i2c_write(0xf0);
  i2c_write(0xaa);
  i2c_stop();
  // --------------------

  // --------------------
  // send 6 zero bytes to register 0x40
  i2c_start_wait(CONTROLLER_ADDR | I2C_WRITE);
  i2c_write(0x40);

  for (uint8_t i = 0; i < 6; i++)
    i2c_write(0x00);

  i2c_stop();
  // --------------------

  // --------------------
  // send 6 zero bytes to register 0x40
  i2c_start_wait(CONTROLLER_ADDR | I2C_WRITE);
  i2c_write(0x40);

  for (uint8_t i = 0; i < 6; i++)
    i2c_write(0x00);

  i2c_stop();
  // --------------------

  // --------------------
  // send 4 zero bytes to register 0x40
  i2c_start_wait(CONTROLLER_ADDR | I2C_WRITE);
  i2c_write(0x40);

  for (uint8_t i = 0; i < 4; i++)
    i2c_write(0x00);

  i2c_stop();
  // --------------------
}

uint8_t controller_read(ContollerData *cd) {
  // --------------------
  // read 6 bytes
  if (i2c_start(CONTROLLER_ADDR | I2C_READ) != 0) {
    return FALSE;
  }

  uint8_t i = 0;

  for (i = 0; i < 5; i++) {
    cd->byte[i] = i2c_readAck(); // i2c_read(I2C_ACK);
  }

  cd->byte[i] = (i2c_readNak()); // i2c_read(I2C_NOACK);
  i2c_stop();
  // --------------------

  // --------------------
  // send read request to 0x00 register
  // for the next bytes!!!!
  // NOTE this is very important for original Nintendo Controller
  i2c_start(CONTROLLER_ADDR | I2C_WRITE);
  i2c_write(0x00);
  i2c_stop();
  // --------------------

  return TRUE;
}


static void read_id(uint8_t id[6]) {
  // --------------------
  // send read request to 0xfa register
  i2c_start(CONTROLLER_ADDR | I2C_WRITE);
  i2c_write(0xFA);
  i2c_stop();
  // --------------------

  // --------------------
  // read 6 bytes
  if (i2c_start(CONTROLLER_ADDR | I2C_READ) != 0) {
    return; // if controller is not responsing
  }

  uint8_t i = 0;

  for (i = 0; i < 5; i++) {
    id[i] = i2c_readAck(); // i2c_read(I2C_ACK);
  }

  id[i] = (i2c_readNak()); // i2c_read(I2C_NOACK);
  i2c_stop();
  // --------------------
}

const uint8_t ID_MAP[MAX_IDs][6] PROGMEM = {
  {0xff, 0xff, 0xff, 0xff, 0xff, 0xff}, // ID_Unknown
  {0x00, 0x00, 0xa4, 0x20, 0x00, 0x00}, // ID_Nunchuck
  {0x00, 0x00, 0xa4, 0x20, 0x01, 0x01}, // ID_Wii_Classic
  {0x01, 0x00, 0xa4, 0x20, 0x01, 0x01}, // ID_Wii_Classic_Pro
  {0x01, 0x00, 0xa4, 0x20, 0x00, 0x01}, // ID_NES_Classic_Mini_Clone_Encrypted
  {0x00, 0x00, 0xa4, 0x20, 0x00, 0x01}  // ID_8Bitdo_SF30
};

ControllerID get_id(void) {
  uint8_t id[6];

  memset(id, 0, 6);
  read_id(id);

  // --------------------
  // compare the 6 bytes with known IDs
  for (uint8_t i = 0; i < MAX_IDs; i++) {

    // known controller found?
    if (memcmp_P(&id[0], &ID_MAP[i][0], 6) == 0) {

      switch (i) {
        case ID_Unknown:
          controller_init();
          read_id(id); // update id
          continue;

        case ID_Wii_Classic: {
          ContollerData data;
          controller_read(&data);

          // look if controller sends wired data (8Bitdo_SF30)
          // needs init & encryption afterwards
          if (data.byte[4] == 0x00 && data.byte[5] == 0x00) {
            controller_init();
            controller_disable_encryption();
          }
        }
        break;

        case ID_Wii_Classic_Pro: {
          ContollerData data;
          controller_read(&data);

          // look if controller sends wired data
          // NES Classic Mini Wireless Clone needs encryption & init afterwards
          if (data.byte[4] == 0x00 && data.byte[5] == 0x00) {
            controller_disable_encryption();
            controller_init();
          }
        }
        break;

        case ID_NES_Classic_Mini_Clone_Encrypted:
          controller_disable_encryption();
          controller_init();
          break;

        case ID_8Bitdo_SF30:
          controller_init();
          controller_disable_encryption();

          read_id(id);

          // if controller id has changed, then it is not a ID_8Bitdo_SF30
          // Chinese Item# JYS-NS126 has also same ID, but doesn't need encryption
          if (memcmp_P(&id[0], &ID_MAP[i][0], 6) != 0) {
            controller_init();
          }

          break;

      } // switch

      return i;
    }
  }

  // --------------------

  return MAX_IDs; // no known controller found, return MAX_IDs
}

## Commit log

2017-12-30 added some files
    [nunchuk64.kicad_pcb, nunchuk64.sch]
2017-12-30 added gerber files
    [nunchuk64-B.Cu.gbl, nunchuk64-B.Mask.gbs, nunchuk64-B.SilkS.gbo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]
2018-01-15 added driver struct, added some helper marcos
2018-01-16 changed driver base, added nunchuk driver, added detection
2018-01-21 added button, led and selector modules
2018-01-23 added driver wii classic
2018-02-01 added ID of NES classic mini chinese clone, improved driver
2018-02-01 added missing kicad libraries
2018-02-02 bugfixed nunchuk init, cleanup, nunchuck accelerometer
2018-02-02 fixed Make fuses
2018-02-10 added more led states, changed paddle code
2018-02-14 fixed controller identification and encryption
    [controller.c]
2018-02-14 led blink code with timer
2018-02-14 removed led_poll call in mainloop
2018-02-22 made i2c bus faster, added DEFINES for single controller config
2018-02-26 fixed problems with original nunchuk
    [controller.c, nunchuk64.c]
2018-02-28 added cosmetic change in layout
    [nunchuk64.kicad_pcb, nunchuk64.sch]
2018-03-01 added timer files
2018-03-04 changed layout a bit
    [nunchuk64.kicad_pcb]
2018-03-04 new gerber files
    [nunchuk64-B.Cu.gbl, nunchuk64-B.Mask.gbs, nunchuk64-B.SilkS.gbo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]
2018-03-05 update schematic.pdf and 3d pic
2018-03-09 changed led behaviour a bit
2018-03-10 reset joystick state, after disconnect, added old timings, nunchuk more sensitive
    [controller.c, nunchuk64.c]
2018-03-12 removed F3 mode, switch ports now with longer button press
2018-03-18 added led feedback for long press joystick switch
2018-05-09 added assembly_instruction
2018-05-14 added assembly_instruction english, changed german
2018-05-15 commented nes classic driver code
2018-07-18 added support for 8bitdo RT und LT buttons
2018-12-19 Update README.md
    added BOM
2019-05-06 added cases/README.md
    [nunchuk64.sch]
2020-11-12 throughole version
    [nunchuk64-tht.kicad_pcb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]
2021-03-08 nunchuk64-throughole version. bom with mouser parts.
    [nunchuk64-tht.csv, nunchuk64-tht.kicad_pcb]
2021-03-08 refreshed gerber files
    [nunchuk64-tht-B_Cu.gbl, nunchuk64-tht-B_Mask.gbs, nunchuk64-tht-B_SilkS.gbo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]
2021-11-08 Update README.md
    https://forum.kicad.info/t/warning-avoid-all-links-to-kicad-pcb-org-use-kicad-org/31521
2022-05-26 fixed problem with traces shortcircuiting
    [nunchuk64-tht-B_Cu.gbl, nunchuk64-tht-B_Mask.gbs, nunchuk64-tht-B_SilkS.gbo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]
2022-05-26 removed gerber.zip. Double-documentation == problems.

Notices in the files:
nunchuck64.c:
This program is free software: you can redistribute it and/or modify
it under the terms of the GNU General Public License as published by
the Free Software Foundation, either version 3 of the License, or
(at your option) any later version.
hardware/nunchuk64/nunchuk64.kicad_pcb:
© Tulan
